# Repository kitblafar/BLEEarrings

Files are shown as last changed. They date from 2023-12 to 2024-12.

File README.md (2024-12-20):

# Bluetooth Low-Energy Earrings

A set of bluetooth BLE earrings inspired by the movie blade runner.

Including custom pendant, earring and earring charging dock PCBs; custom 3D printed enclosure; embedded solution on NRF52833 and bluetooth app.

This earring blink different colours dependant on messages sent over Bluetooth by the bluetooth app. The solution includes a pendant that holds the LED and is connected by wiring that passes through the ear piercing; the earring itself that sits behind the ear and a charging and programming dock including USB hub. The earrings are flashed and charged over USB C connectors and are powered by drone batteries so include custom charge protection and power path management circuits.

Project phase: PCB ordered and received, BOM finalised and ordered, first revision of enclosure made, first iteration of the embedded solution.

Next step: test PCBs and NRF52833 code, order batteries, print enclosure, start developing the app.

This is a collab with [Dominic Mason](https://github.com/dominicmason555/)

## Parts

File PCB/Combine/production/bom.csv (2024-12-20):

Designator | Footprint | Quantity | Value | LCSC Part #
ANT1, ANT2 | Texas_SWRA117D_2.4GHz_Left | 2 | ~ | N/A
BT1 | CONN-TH_S2B-PH-K-S-LF-SN | 1 | Battery Pimoroni 1200mAh | C173752
BT2, BT3 | CONN-TH_530480210 | 2 | Battery Gens ace 200mAh 1S 45C 3.7V | C505099
C1, C11, C13, C16, C19, C2, C20 | 0402 | 7 | 100n | C60474
C10, C9 | 0603 | 2 | 22u | C59461
C12, C14, C23, C3 | 0402 | 4 | 1u | C14445
C15, C17 | 0402 | 2 | 4.7u
C18 | 0402 | 1 | 100n
C21, C22 | 0402 | 2 | 18p | C5137554
C24, C26, C59, C61 | 0402 | 4 | 10u | C15525
C25, C30, C33, C41, C46, C49, C57, C60 | 0402 | 8 | 100n | C60474
C27, C32, C43, C48 | 0402 | 4 | 8p | C5448809
C28, C29, C31, C44, C45, C47 | 0402 | 6 | 4.7u | C307423
C34, C38, C50, C54 | 0402 | 4 | 1u | C14445
C35, C51 | 0402 | 2 | 1p | C880647
C36, C52 | 0402 | 2 | 100p | C5137573
C37, C53 | 0402 | 2 | 1.2p | C880658
C39, C55 | 0402 | 2 | NC | N/A
C4, C5 | 0402 | 2 | 2.2u | C12530
C40, C42, C56, C58 | 0402 | 4 | 12p | C696888
C6, C7 | 0402 | 2 | 4.7u | C307423
C63, C64 | 0402 | 2 | 100n | C5448809
C8 | 0402 | 1 | 10u | C15525
D1 | 0603 | 1 | LED
D10, D8 | 0603 | 2 | BLUE LED | C7371904
D11, D7 | 0603 | 2 | RED LED | C389517
D12, D13 | LED-SMD_4P-L1.6-W1.5_XL-1615RGBC-WS2812B | 2 | 2758
D2 | 0603 | 1 | BLUE RED | C389517
D3, D4, D5 | 0603 | 3 | BLUE LED | C7371904
D6, D9 | SOT-23-6_L2.9-W1.6-P0.95-LS2.8-BL | 2 | USBLC6-2SC6_C2687116 | C2687116
J1 | TYPE-C-SMD_C9900025773 | 1 | USB_C_Receptacle | C5156605
J2 | HDR-TH_10P-P1.27-V-M-R2-C5-S1.27-1 | 1 | Conn_01x10_Socket | C2935953
J3, J6 | TYPE-C-SMD_C9900025773 | 2 | USB_C_Receptacle | C5156605
J4, J7 | CONN-SMD_custom1 | 2 | Screw_Terminal_01x01 | C2765059
J5, J8 | CONN-SMD_2059-302 | 2 | Screw_Terminal_01x02 | C2765060
L1 | IND-SMD_L4.5-W4.1 | 1 | 4.7u | C22463808
L2, L4 | 0402 | 2 | 4.7n | C13595
L3, L5 | 0402 | 2 | 2.2n | C395061
P1, P2 | USB-C-SMD_TYPE-C-24P-GTJB-040 | 2 | USB_C_Plug | C2763095
R1, R24, R25, R38, R39, R4 | 0402 | 6 | 5k1 | C103086
R10 | 0402 | 1 | 2k | C3016052
R11, R12 | 0402 | 2 | 1k | C3016052
R13 | 0402 | 1 | 732 | C137939
R14 | 0402 | 1 | 100k | C60491
R15, R16, R29, R40 | 0402 | 4 | 220 | C112291
R17, R18, R19 | 0402 | 3 | 100 | C3015757
R20 | 0402 | 1 | 12k | C137923
R21, R22 | 0402 | 2 | 10k
R23, R9 | 0402 | 2 | 10k | C60490
R26, R37, R48, R49 | 0402 | 4 | 2k | C60488
R27, R50 | 0402 | 2 | 4k99 | C137965
R28, R51 | 0402 | 2 | 100 | C106233
R30, R31, R32, R33, R41, R42, R43, R44 | 0201 | 8 | NF | N/A
R34, R45 | 0402 | 2 | 100k | C60491
R35, R46 | 0402 | 2 | 33k | C138003
R36, R47 | 0402 | 2 | 470 | C114949
R5, R6 | 0402 | 2 | 1k | C60488
R7 | 0402 | 1 | 1.18k | C3016052
R8 | 0402 | 1 | 1.78k | C5121514
SW1, SW3 | SW-TH_TK-6580B-1 | 2 | TK-6580B-1 | C2689829
SW2, SW4 | KEY-SMD_L3.0-W2.5-LS4.0 | 2 | SW_DIP_x01 | C2905194
TP1, TP10, TP11, TP12, TP2, TP28, TP3, TP4, TP5, TP6, TP7, TP8, TP9, TPL3 | TestPoint_Pad_D1.0mm | 14 | TestPoint
TP13, TP14, TP15, TP17, TP18, TP19 | TestPoint_Pad_D1.0mm | 6 | TestPoint | N/A
TP16, TP20 | TestPoint_Pad_D2.0mm | 2 | TestPoint | N/A
TP21, TP22, TP23, TP24, TP25, TP26 | TestPoint_THTPad_D1.0mm_Drill0.5mm | 6 | TestPoint
U1 | SOT-223-3_TabPin2 | 1 | AMS1117-3.3 | N/A
U10, U9 | QFN-40_L5.0-W5.0-P0.40-TL-EP3.6 | 2 | NRF52833-QDAA-R7 | C3007767
U11, U7 | SOT-23-5_L3.0-W1.7-P0.95-LS2.8-BL | 2 | MCP73831T-2ACI/OT | C424093
U12, U8 | WDFN-6_L2.0-W2.0-P0.65-BL-EP | 2 | XB6096I2SV | C2998744
U2 | VQFN-16-1EP_3x3mm_P0.5mm_EP1.6x1.6mm | 1 | BQ24073RGT | C15220
U3 | SOT-563_L1.6-W1.2-P0.50-LS1.6-BR | 1 | TPS61023DRLR | C919459
U4, U6 | SOT-23-6_Handsoldering | 2 | SIP32509DT-T1-GE3 | C335619
U5 | HVQFN-24-1EP_4x4mm_P0.5mm_EP2.5x2.5mm_ThermalVias | 1 | USB2422T-I/MJ | C622610
Y1 | CRYSTAL-SMD_4P-L3.2-W2.5-BL | 1 | X322524MOB4SI | C70590
Y2, Y4 | CRYSTAL-SMD_L1.6-W1.0 | 2 | X161032768KLD2SI | C383846
Y3, Y5 | CRYSTAL-SMD_4P-L2.0-W1.6-BL | 2 | XL7EL89CKI-111YLC-32M | C2965582

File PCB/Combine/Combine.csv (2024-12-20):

Reference | Value | Footprint | Datasheet | Availability | Check_prices | Description | LCSC Part | MANUFACTURER | MAXIMUM_PACKAGE_HEIGHT | MF | MP | PARTREV | Package | Price | STANDARD | SnapEDA_Link | Qty
ANT1, ANT2 | ~ | RF_Antenna:Texas_SWRA117D_2.4GHz_Left |  |  |  |  | N/A |  |  |  |  |  |  |  |  |  | 2
BT1 | Battery Pimoroni 1200mAh | easyeda2kicad:CONN-TH_S2B-PH-K-S-LF-SN | ~ |  |  |  | C173752 |  |  |  |  |  |  |  |  |  | 1
BT2, BT3 | Battery Gens ace 200mAh 1S 45C 3.7V | easyeda2kicad:CONN-TH_530480210 | ~ |  |  |  | C505099 |  |  |  |  |  |  |  |  |  | 2
C1, C2, C11, C13, C16, C18-C20, C25, C30, C33, C41, C46, C49, C57, C60, C63, C64 | 100n | Capacitor_SMD:C_0402_1005Metric_Pad0.74x0.62mm_HandSolder | ~ |  |  |  | -- mixed values -- |  |  |  |  |  |  |  |  |  | 18
C3, C12, C14, C23, C34, C38, C50, C54 | 1u | Capacitor_SMD:C_0402_1005Metric_Pad0.74x0.62mm_HandSolder | ~ |  |  |  | -- mixed values -- |  |  |  |  |  |  |  |  |  | 8
C4, C5 | 2.2u | Capacitor_SMD:C_0402_1005Metric_Pad0.74x0.62mm_HandSolder | ~ |  |  |  | C12530 |  |  |  |  |  |  |  |  |  | 2
C6, C7, C15, C17, C28, C29, C31, C44, C45, C47 | 4.7u | Capacitor_SMD:C_0402_1005Metric_Pad0.74x0.62mm_HandSolder | ~ |  |  |  | -- mixed values -- |  |  |  |  |  |  |  |  |  | 10
C8, C24, C26, C59, C61 | 10u | Capacitor_SMD:C_0402_1005Metric_Pad0.74x0.62mm_HandSolder | ~ |  |  |  | -- mixed values -- |  |  |  |  |  |  |  |  |  | 5
C9, C10 | 22u | Capacitor_SMD:C_0603_1608Metric_Pad1.08x0.95mm_HandSolder | ~ |  |  |  | C59461 |  |  |  |  |  |  |  |  |  | 2
C21, C22 | 18p | Capacitor_SMD:C_0402_1005Metric_Pad0.74x0.62mm_HandSolder | ~ |  |  |  | C5137554 |  |  |  |  |  |  |  |  |  | 2
C27, C32, C43, C48 | 8p | Capacitor_SMD:C_0402_1005Metric_Pad0.74x0.62mm_HandSolder | ~ |  |  |  | C5448809 |  |  |  |  |  |  |  |  |  | 4
C35, C51 | 1p | Capacitor_SMD:C_0402_1005Metric_Pad0.74x0.62mm_HandSolder | ~ |  |  |  | C880647 |  |  |  |  |  |  |  |  |  | 2
C36, C52 | 100p | Capacitor_SMD:C_0402_1005Metric_Pad0.74x0.62mm_HandSolder | ~ |  |  |  | C5137573 |  |  |  |  |  |  |  |  |  | 2
C37, C53 | 1.2p | Capacitor_SMD:C_0402_1005Metric_Pad0.74x0.62mm_HandSolder | ~ |  |  |  | C880658 |  |  |  |  |  |  |  |  |  | 2
C39, C55 | NC | Capacitor_SMD:C_0402_1005Metric_Pad0.74x0.62mm_HandSolder | ~ |  |  |  | N/A |  |  |  |  |  |  |  |  |  | 2
C40, C42, C56, C58 | 12p | Capacitor_SMD:C_0402_1005Metric_Pad0.74x0.62mm_HandSolder | ~ |  |  |  | C696888 |  |  |  |  |  |  |  |  |  | 4
D1 | LED | LED_SMD:LED_0603_1608Metric_Pad1.05x0.95mm_HandSolder | ~ |  |  |  |  |  |  |  |  |  |  |  |  |  | 1
D2 | BLUE RED | easyeda2kicad:SideStuckLED | ~ |  |  |  | C389517 |  |  |  |  |  |  |  |  |  | 1
D3 | BLUE LED | easyeda2kicad:SideStuckLED | ~ |  |  |  | C7371904 |  |  |  |  |  |  |  |  |  | 1
D4, D5, D8, D10 | BLUE LED | LED_SMD:LED_0603_1608Metric_Pad1.05x0.95mm_HandSolder | ~ |  |  |  | -- mixed values -- |  |  |  |  |  |  |  |  |  | 4
D6, D9 | USBLC6-2SC6_C2687116 | easyeda2kicad:SOT-23-6_L2.9-W1.6-P0.95-LS2.8-BL |  |  |  |  | C2687116 |  |  |  |  |  |  |  |  |  | 2
D7, D11 | RED LED | LED_SMD:LED_0603_1608Metric_Pad1.05x0.95mm_HandSolder | ~ |  |  |  | C389517 |  |  |  |  |  |  |  |  |  | 2
D12, D13 | 2758 | easyeda2kicad:SOL320P540X170-4N |  | In Stock | https://www.snapeda.com/parts/2758/Adafruit+Industries+LLC/view-part/?ref=eda | Addressable Lighting Neopixel 10 LED Discrete Serial (Shift Register) Red, Green, Blue, Neutral White (RGBW) 5.00mm L x 5.00mm W |  | Adafruit Industries | 1.7 mm | Adafruit Industries | 2758 | 01 | SMD-4 Adafruit Industries | None | IPC 7351B | https://www.snapeda.com/parts/2758/Adafruit+Industries+LLC/view-part/?ref=snap | 2
J1, J3, J6 | USB_C_Receptacle | easyeda2kicad:TYPE-C-SMD_C9900025773 | https://www.usb.org/sites/default/files/documents/usb_type-c.zip |  |  |  | -- mixed values -- |  |  |  |  |  |  |  |  |  | 3
J2 | Conn_01x10_Socket | easyeda2kicad:HDR-TH_10P-P1.27-V-M-R2-C5-S1.27-1 | ~ |  |  |  | C2935953 |  |  |  |  |  |  |  |  |  | 1
J4, J7 | Screw_Terminal_01x01 | easyeda2kicad:CONN-SMD_custom1 | ~ |  |  |  | C2765059 |  |  |  |  |  |  |  |  |  | 2
J5, J8 | Screw_Terminal_01x02 | easyeda2kicad:CONN-SMD_2059-302 | ~ |  |  |  | C2765060 |  |  |  |  |  |  |  |  |  | 2
L1 | 4.7u | easyeda2kicad:IND-SMD_L4.4-W4.2 | ~ |  |  |  | C2836880 |  |  |  |  |  |  |  |  |  | 1
L2, L4 | 4.7n | Inductor_SMD:L_0402_1005Metric_Pad0.77x0.64mm_HandSolder | ~ |  |  |  | C13595 |  |  |  |  |  |  |  |  |  | 2
L3, L5 | 2.2n | Inductor_SMD:L_0402_1005Metric_Pad0.77x0.64mm_HandSolder | ~ |  |  |  | C395061 |  |  |  |  |  |  |  |  |  | 2
P1, P2 | USB_C_Plug | easyeda2kicad:USB-C-SMD_TYPE-C-24P-GTJB-040 | https://www.usb.org/sites/default/files/documents/usb_type-c.zip |  |  |  | C2763095 |  |  |  |  |  |  |  |  |  | 2
R1, R4, R24, R25, R38, R39 | 5k1 | Resistor_SMD:R_0402_1005Metric_Pad0.72x0.64mm_HandSolder | ~ |  |  |  | C103086 |  |  |  |  |  |  |  |  |  | 6
R2, R3 | 0R | Resistor_SMD:R_0805_2012Metric_Pad1.20x1.40mm_HandSolder | ~ |  |  |  |  |  |  |  |  |  |  |  |  |  | 2
R5, R6 | 1k | Resistor_SMD:R_0402_1005Metric_Pad0.72x0.64mm_HandSolder | ~ |  |  |  | C60488 |  |  |  |  |  |  |  |  |  | 2
R7, R11, R12 | 1.18k | Resistor_SMD:R_0402_1005Metric_Pad0.72x0.64mm_HandSolder | ~ |  |  |  | C3016052 |  |  |  |  |  |  |  |  |  | 3
R8 | 1.78k | Resistor_SMD:R_0402_1005Metric_Pad0.72x0.64mm_HandSolder | ~ |  |  |  | C5121514 |  |  |  |  |  |  |  |  |  | 1
R9, R21-R23 | 10k | Resistor_SMD:R_0402_1005Metric_Pad0.72x0.64mm_HandSolder | ~ |  |  |  | -- mixed values -- |  |  |  |  |  |  |  |  |  | 4
R10, R26, R37, R48, R49 | 2k | Resistor_SMD:R_0402_1005Metric_Pad0.72x0.64mm_HandSolder | ~ |  |  |  | -- mixed values -- |  |  |  |  |  |  |  |  |  | 5
R13 | 732 | Resistor_SMD:R_0402_1005Metric_Pad0.72x0.64mm_HandSolder | ~ |  |  |  | C137939 |  |  |  |  |  |  |  |  |  | 1
R14, R34, R45 | 100k | Resistor_SMD:R_0402_1005Metric_Pad0.72x0.64mm_HandSolder | ~ |  |  |  | -- mixed values -- |  |  |  |  |  |  |  |  |  | 3
R15, R16, R29, R40 | 220 | Resistor_SMD:R_0402_1005Metric_Pad0.72x0.64mm_HandSolder | ~ |  |  |  | C112291 |  |  |  |  |  |  |  |  |  | 4
R17-R19, R28, R51 | 100 | Resistor_SMD:R_0402_1005Metric_Pad0.72x0.64mm_HandSolder | ~ |  |  |  | -- mixed values -- |  |  |  |  |  |  |  |  |  | 5
R20 | 12k | Resistor_SMD:R_0402_1005Metric_Pad0.72x0.64mm_HandSolder | ~ |  |  |  | C137923 |  |  |  |  |  |  |  |  |  | 1
R27, R50 | 4k99 | Resistor_SMD:R_0402_1005Metric_Pad0.72x0.64mm_HandSolder | ~ |  |  |  | C137965 |  |  |  |  |  |  |  |  |  | 2
R30-R33, R41-R44 | NF | Resistor_SMD:R_0201_0603Metric | ~ |  |  |  | N/A |  |  |  |  |  |  |  |  |  | 8
R35, R46 | 33k | Resistor_SMD:R_0402_1005Metric_Pad0.72x0.64mm_HandSolder | ~ |  |  |  | C138003 |  |  |  |  |  |  |  |  |  | 2
R36, R47 | 470 | Resistor_SMD:R_0402_1005Metric_Pad0.72x0.64mm_HandSolder | ~ |  |  |  | C114949 |  |  |  |  |  |  |  |  |  | 2
SW1, SW3 | TK-6580B-1 | easyeda2kicad:SW-TH_TK-6580B-1 |  |  |  |  | C2689829 |  |  |  |  |  |  |  |  |  | 2
SW2, SW4 | SW_DIP_x01 | easyeda2kicad:KEY-SMD_L3.0-W2.5-LS4.0 | ~ |  |  |  | C2905194 |  |  |  |  |  |  |  |  |  | 2
TP1-TP15, TP17-TP19 | TestPoint | TestPoint:TestPoint_Pad_D1.0mm | ~ |  |  |  | -- mixed values -- |  |  |  |  |  |  |  |  |  | 18
TP16, TP20, TP27 | TestPoint | TestPoint:TestPoint_Pad_D2.0mm | ~ |  |  |  | N/A |  |  |  |  |  |  |  |  |  | 3
TP21-TP26 | TestPoint | TestPoint:TestPoint_THTPad_D1.0mm_Drill0.5mm | ~ |  |  |  |  |  |  |  |  |  |  |  |  |  | 6
U1 | AMS1117-3.3 | Package_TO_SOT_SMD:SOT-223-3_TabPin2 | http://www.advanced-monolithic.com/pdf/ds1117.pdf |  |  |  | N/A |  |  |  |  |  |  |  |  |  | 1
U2 | BQ24073RGT | Package_DFN_QFN:VQFN-16-1EP_3x3mm_P0.5mm_EP1.6x1.6mm | http://www.ti.com/lit/ds/symlink/bq24073.pdf |  |  |  | C15220 |  |  |  |  |  |  |  |  |  | 1
U3 | TPS61023DRLR | easyeda2kicad:SOT-563_L1.6-W1.2-P0.50-LS1.6-BR |  |  |  |  | C919459 |  |  |  |  |  |  |  |  |  | 1
U4, U6 | SIP32509DT-T1-GE3 | Package_TO_SOT_SMD:SOT-23-6_Handsoldering | https://lcsc.com/product-detail/Others_Vishay-Intertech-SIP32509DT-T1-GE3_C335619.html |  |  |  | C335619 |  |  |  |  |  |  |  |  |  | 2
U5 | USB2422T-I/MJ | Package_DFN_QFN:HVQFN-24-1EP_4x4mm_P0.5mm_EP2.5x2.5mm_ThermalVias |  |  |  |  | C622610 |  |  |  |  |  |  |  |  |  | 1
U7, U11 | MCP73831T-2ACI/OT | easyeda2kicad:SOT-23-5_L3.0-W1.7-P0.95-LS2.8-BL | https://lcsc.com/product-detail/PMIC-Battery-Management_Microchip-Tech-MCP73831T-2ACI-OT_C424093.html |  |  |  | C424093 |  |  |  |  |  |  |  |  |  | 2
U8, U12 | XB6096I2SV | easyeda2kicad:WDFN-6_L2.0-W2.0-P0.65-BL-EP |  |  |  |  | C2998744 |  |  |  |  |  |  |  |  |  | 2
U9, U10 | NRF52833-QDAA-R7 | easyeda2kicad:QFN-40_L5.0-W5.0-P0.40-TL-EP3.6 |  |  |  |  | C3007767 |  |  |  |  |  |  |  |  |  | 2
Y1 | X322524MOB4SI | easyeda2kicad:CRYSTAL-SMD_4P-L3.2-W2.5-BL | ~ |  |  |  | C70590 |  |  |  |  |  |  |  |  |  | 1
Y2, Y4 | X161032768KLD2SI | easyeda2kicad:CRYSTAL-SMD_L1.6-W1.0 | ~ |  |  |  | C383846 |  |  |  |  |  |  |  |  |  | 2
Y3, Y5 | XL7EL89CKI-111YLC-32M | easyeda2kicad:CRYSTAL-SMD_4P-L2.0-W1.6-BL | ~ |  |  |  | C2965582 |  |  |  |  |  |  |  |  |  | 2

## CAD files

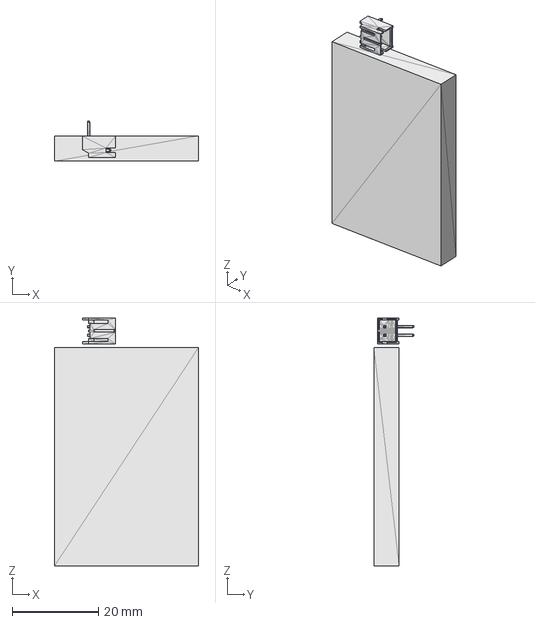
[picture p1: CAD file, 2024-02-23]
CAD/CustomParts/Battery/BatteryDock.STEP
33.5 x 9.40 x 57.6 mm

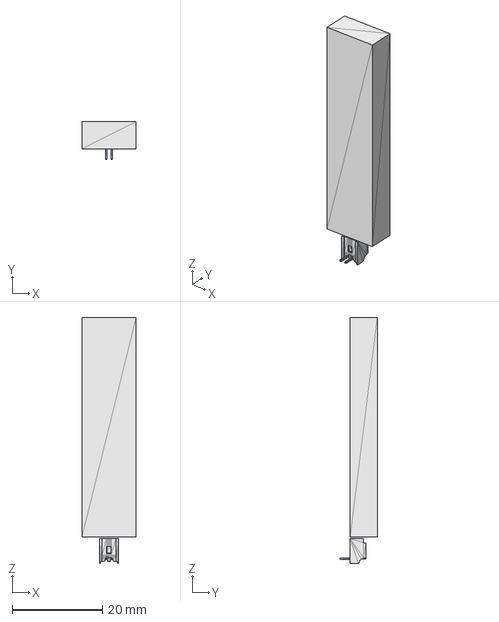
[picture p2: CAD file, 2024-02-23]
CAD/CustomParts/Battery/Earring/BatteryGens.STEP
12.0 x 8.30 x 54.4 mm

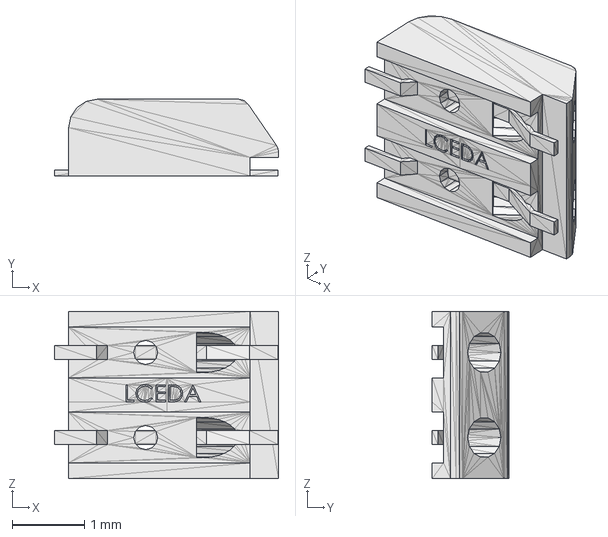
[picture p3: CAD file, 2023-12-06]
CAD/CustomParts/Connector/2Way/2wayconn.step
3.11 x 1.06 x 2.32 mm

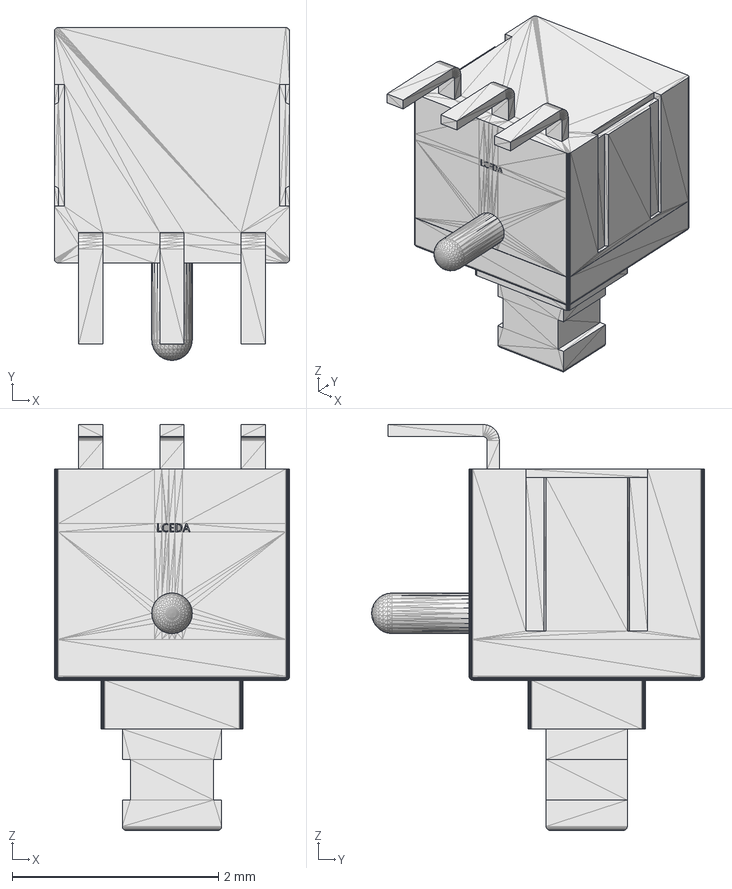
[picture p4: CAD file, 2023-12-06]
CAD/CustomParts/Switch/Switch.step
2.28 x 3.23 x 3.94 mm

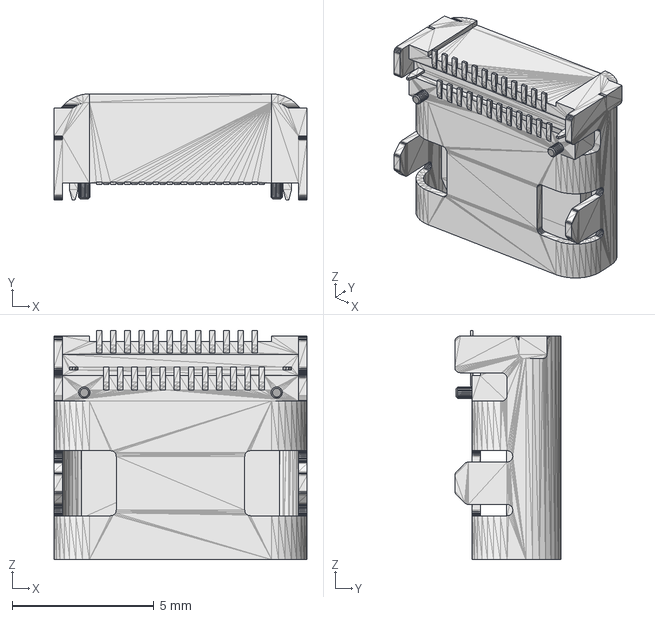
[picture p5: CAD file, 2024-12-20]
CAD/CustomParts/USB-C/USBC.step
8.94 x 3.76 x 8.10 mm

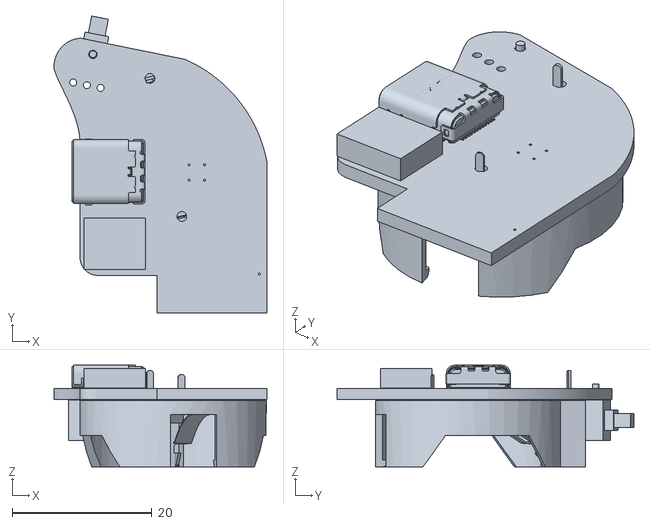
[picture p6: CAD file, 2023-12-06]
CAD/Earrings.stl
30.5 x 42.5 x 14.6

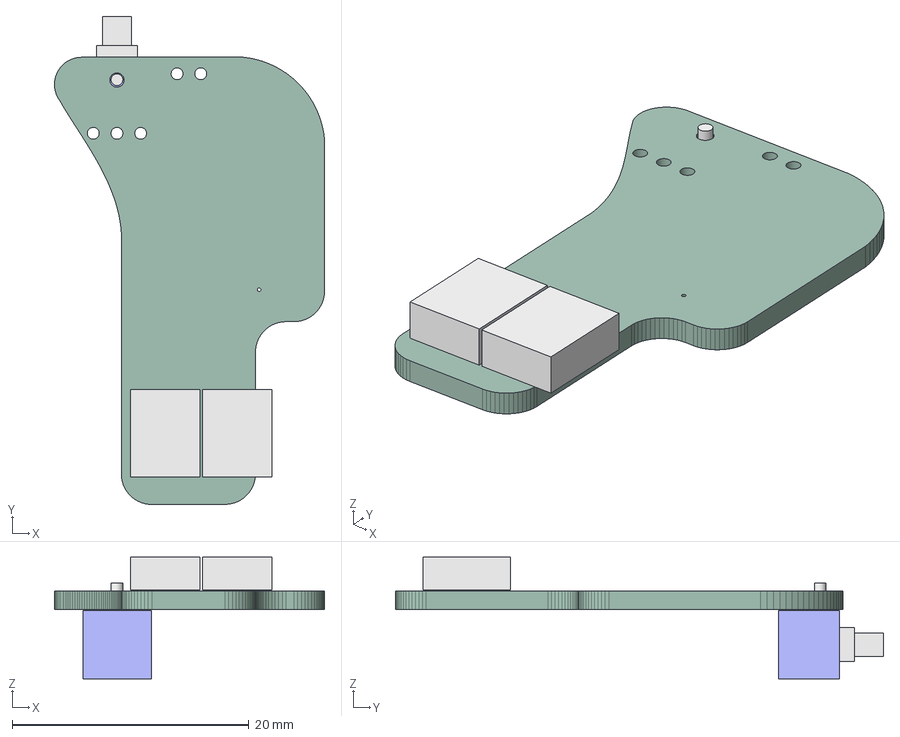
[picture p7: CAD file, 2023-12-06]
KiCADWork/BLEEarrings nRF52832/BLEEarrings.step
22.8 x 41.2 x 10.3 mm
_autosave-BLEEarrings PCB

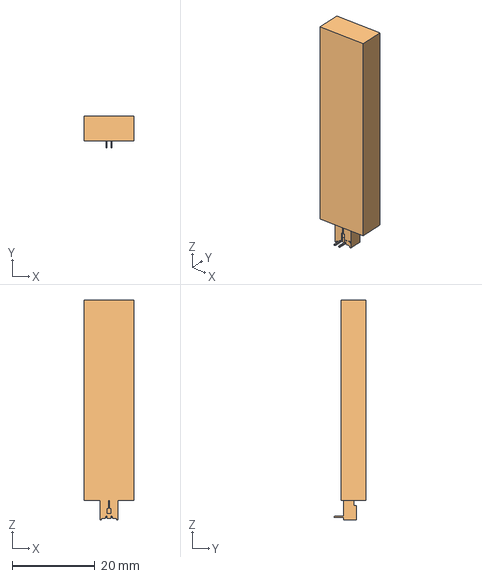
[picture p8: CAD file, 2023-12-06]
CAD/CustomParts/Battery/Earring/Battery.FCStd
12.0 x 7.72 x 53.3 mm
BatteryGens001
BatteryGens

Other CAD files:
CAD/CustomParts/Battery/BatteryDock.blend
CAD/CustomParts/Battery/BatteryDock.stl
CAD/CustomParts/Battery/Earring.blend
CAD/CustomParts/Battery/Earring/BatteryGens.blend
CAD/CustomParts/Battery/Earring/BatteryGens.stl
CAD/CustomParts/Connector/2Way/2Wayconn.FCStd
CAD/CustomParts/Connector/2Way/2wayconn.blend
CAD/CustomParts/Connector/2Way/2wayconn.stl
CAD/CustomParts/Switch/Switch.FCStd
CAD/CustomParts/Switch/Switch.blend
CAD/CustomParts/Switch/Switch.stl
CAD/CustomParts/USB-C/USBC.FCStd
CAD/CustomParts/USB-C/USBC.blend
CAD/CustomParts/USB-C/USBC.stl

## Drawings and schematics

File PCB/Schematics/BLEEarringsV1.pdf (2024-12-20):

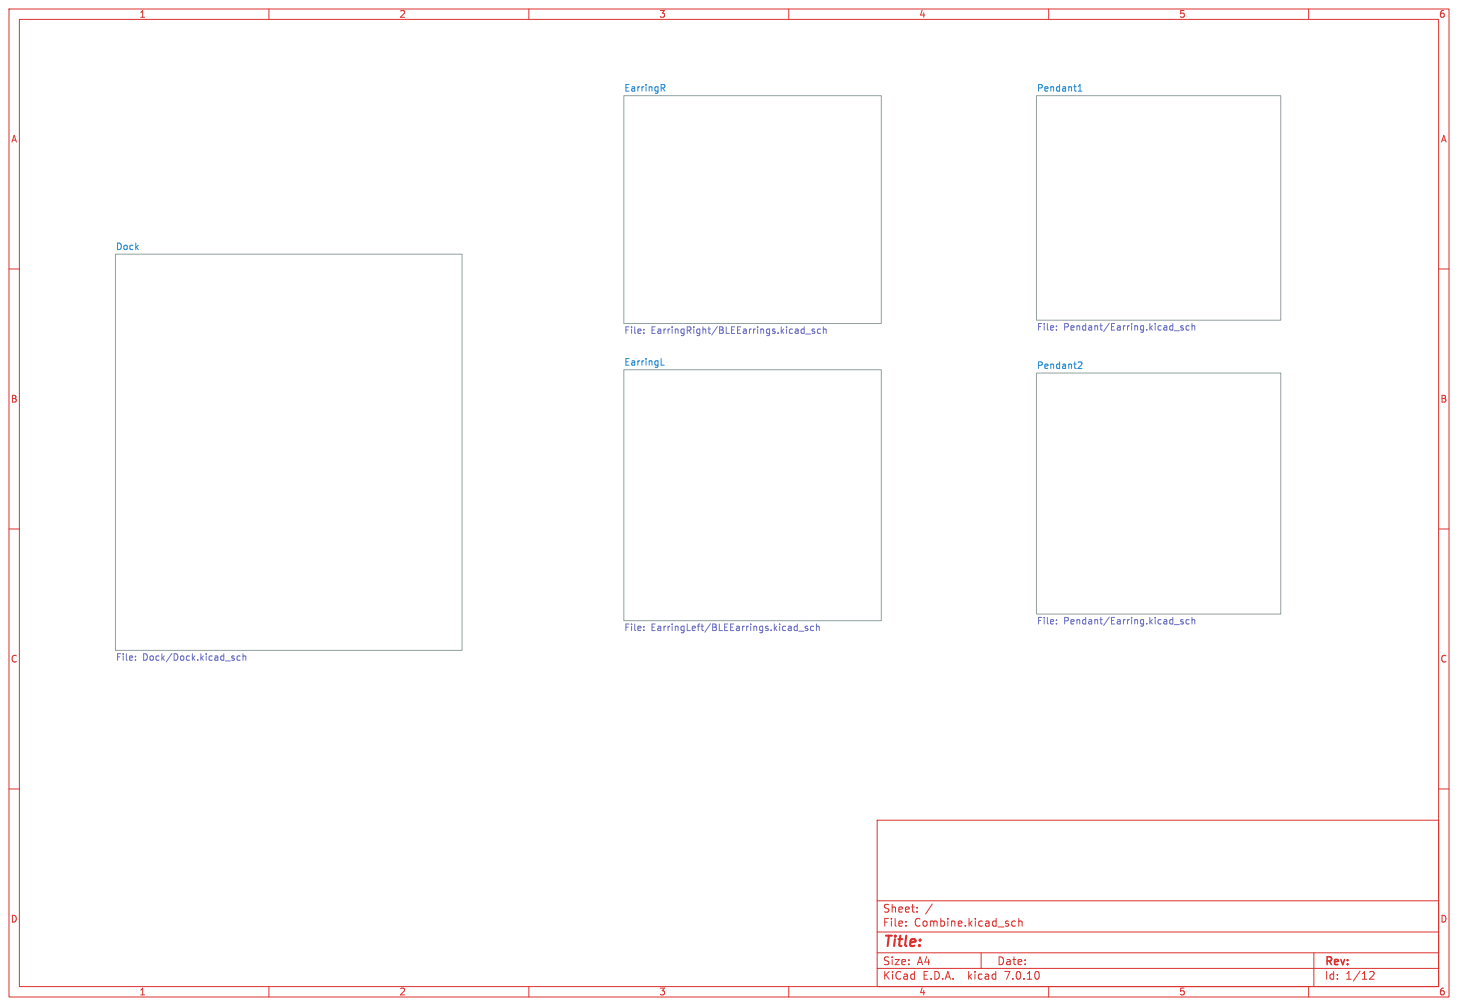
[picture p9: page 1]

EarringL File: EarringLeft/BLEEarrings.kicad_sch

Id: 1/12 Title: File: Combine.kicad_sch Sheet: /

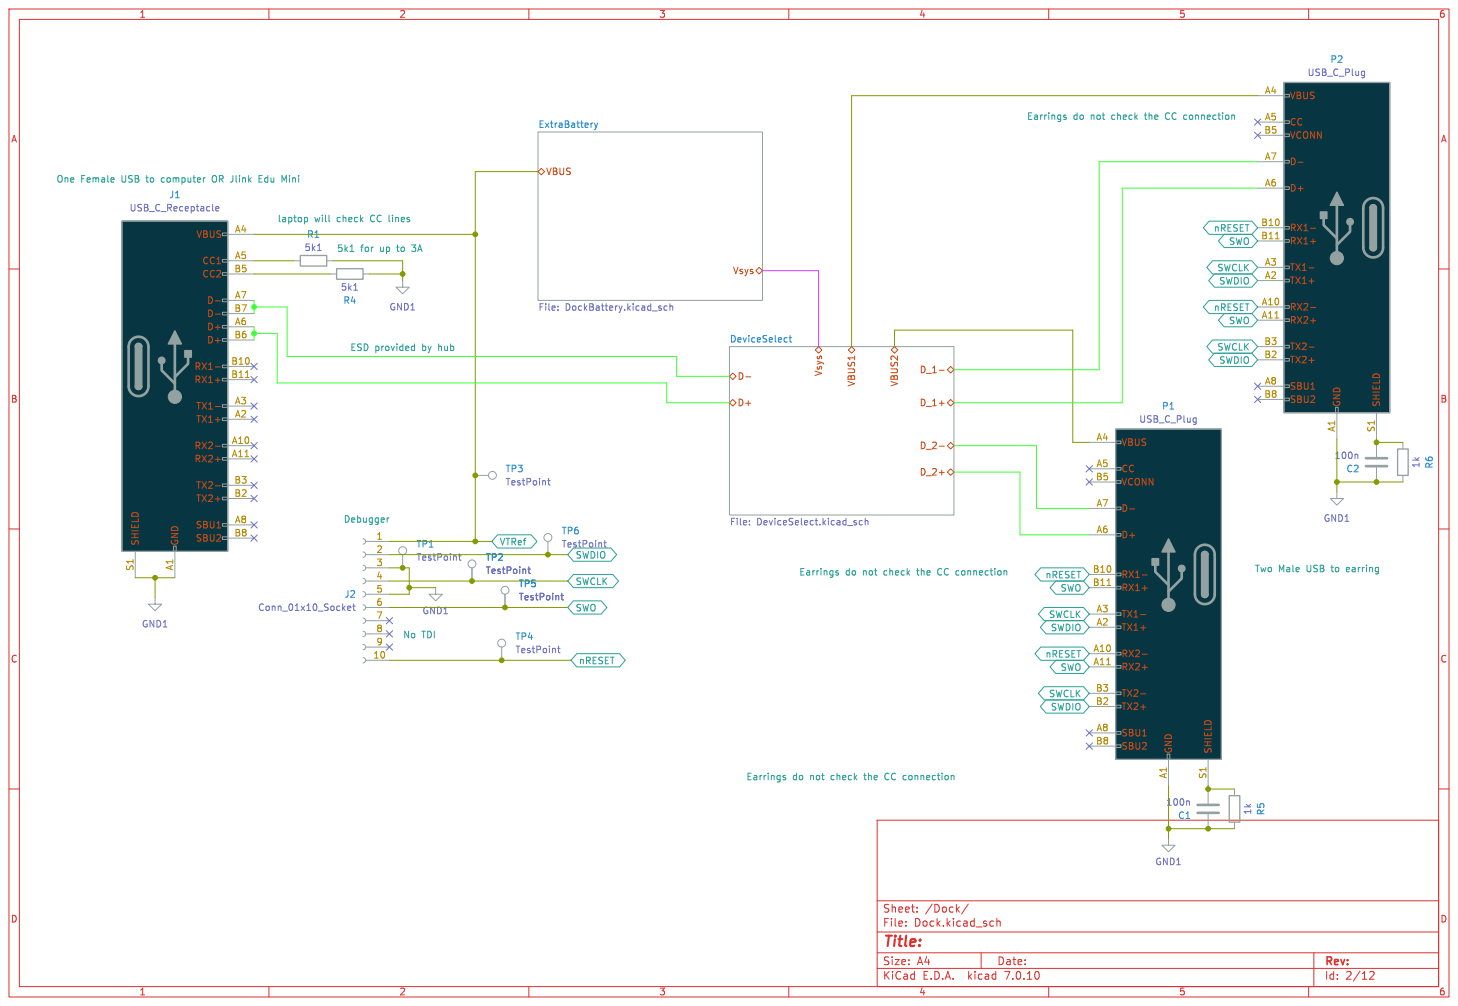
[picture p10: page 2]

Earrings do not check the CC connection

Id: 2/12 Title: File: Dock.kicad_sch Sheet: /Dock/

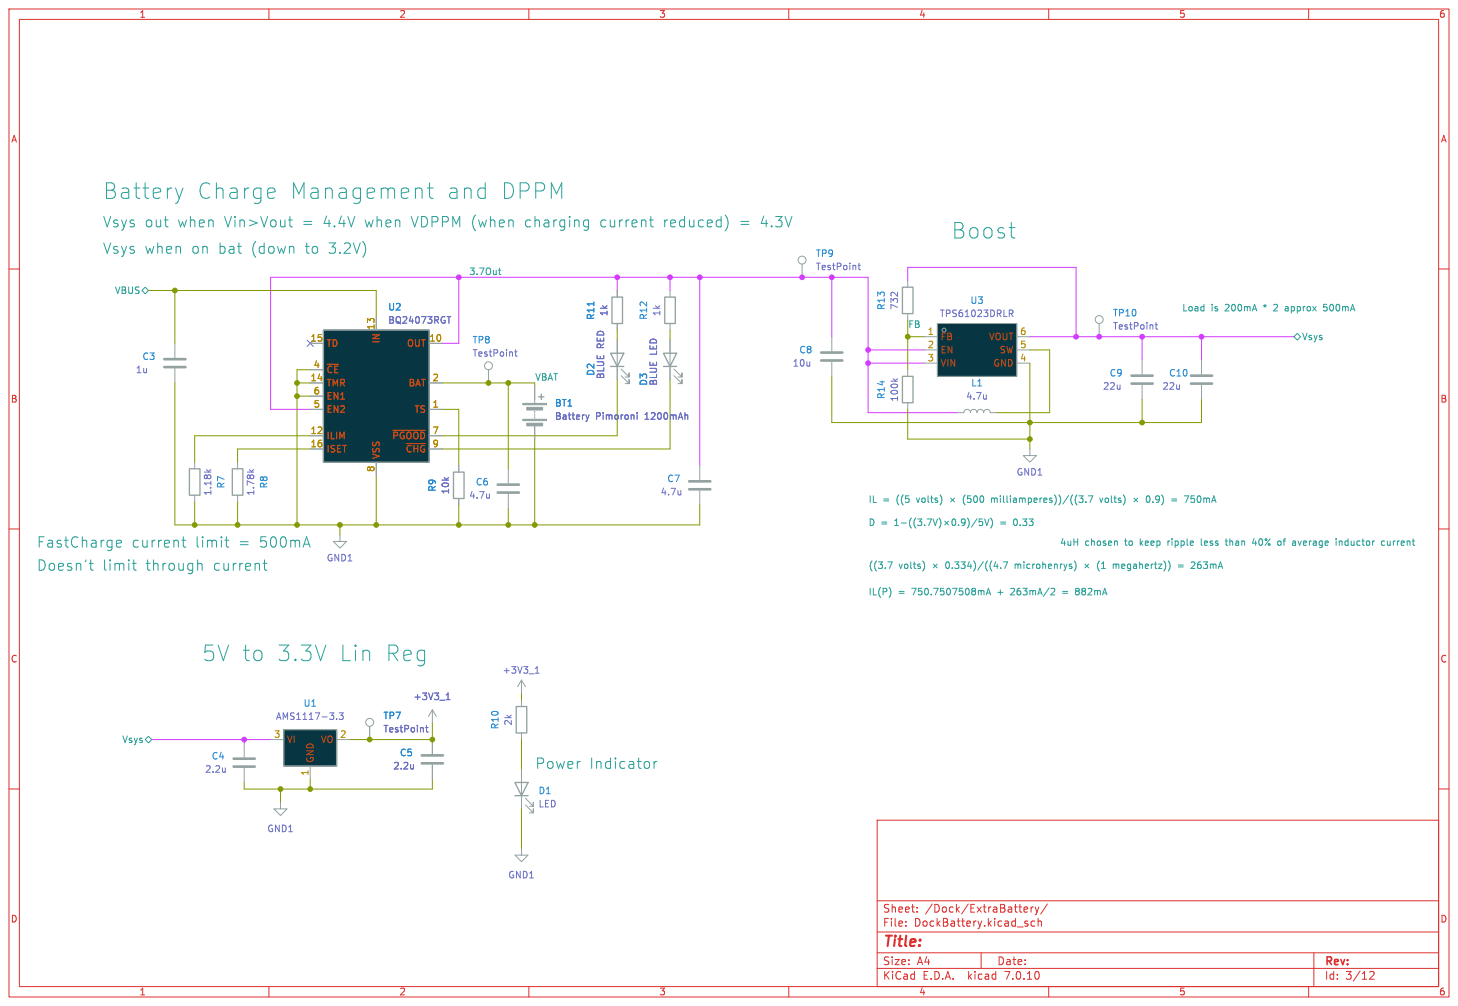
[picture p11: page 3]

Battery Charge Management and DPPM

Load is 200mA * 2 approx 500mA Vsys out when Vin>Vout = 4.4V when VDPPM (when charging current reduced) = 4.3V
Vsys when on bat (down to 3.2V)

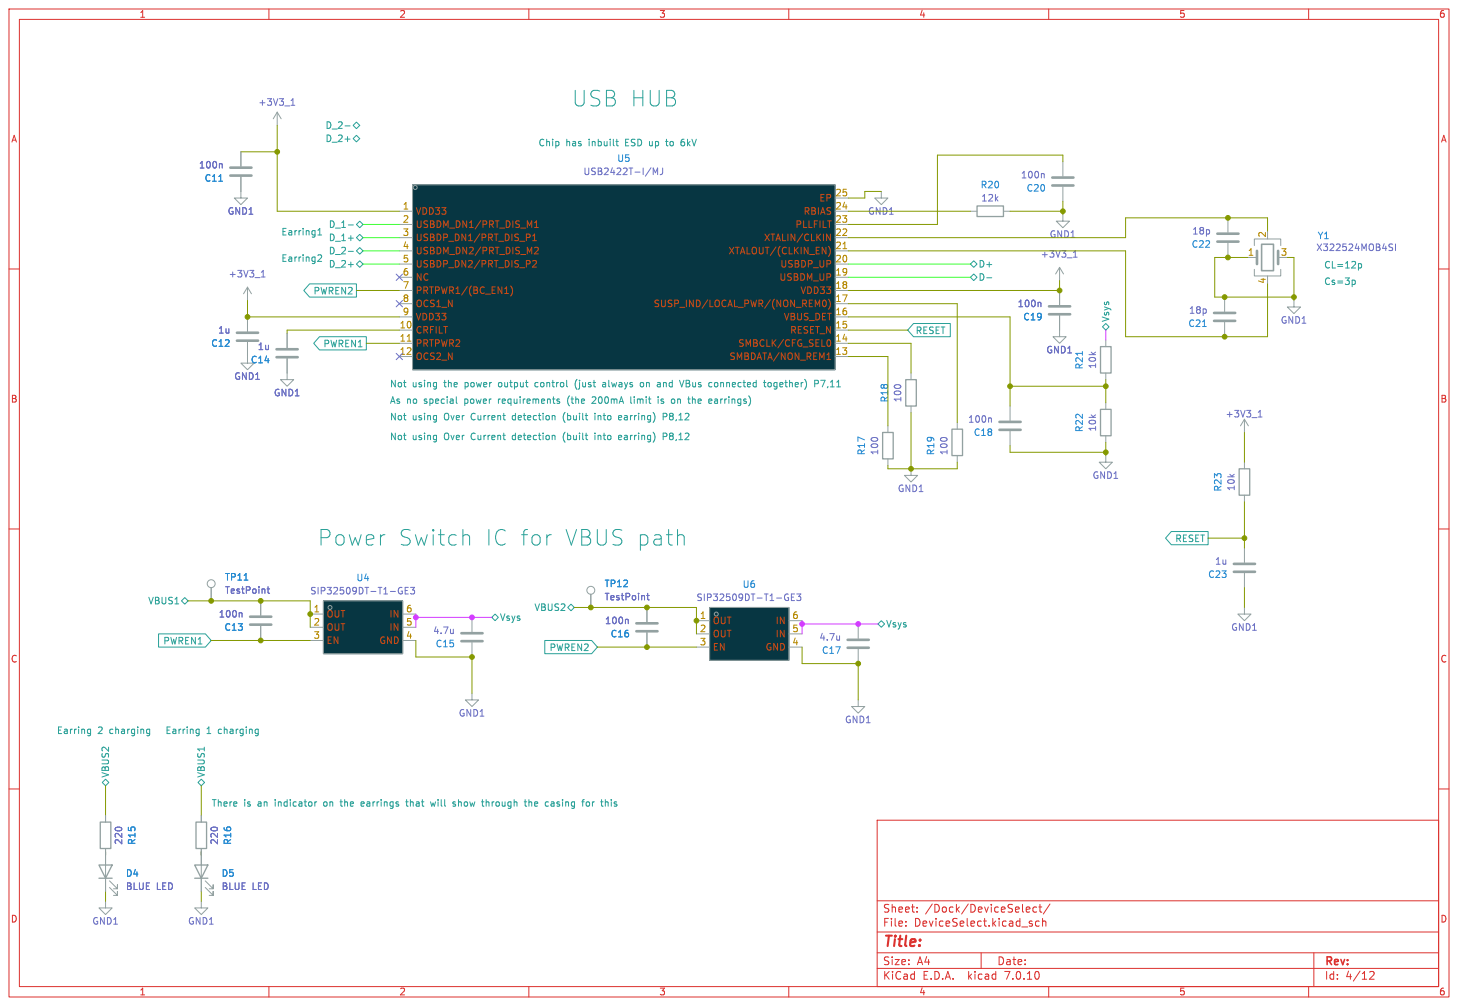
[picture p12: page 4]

Power Switch IC for VBUS path

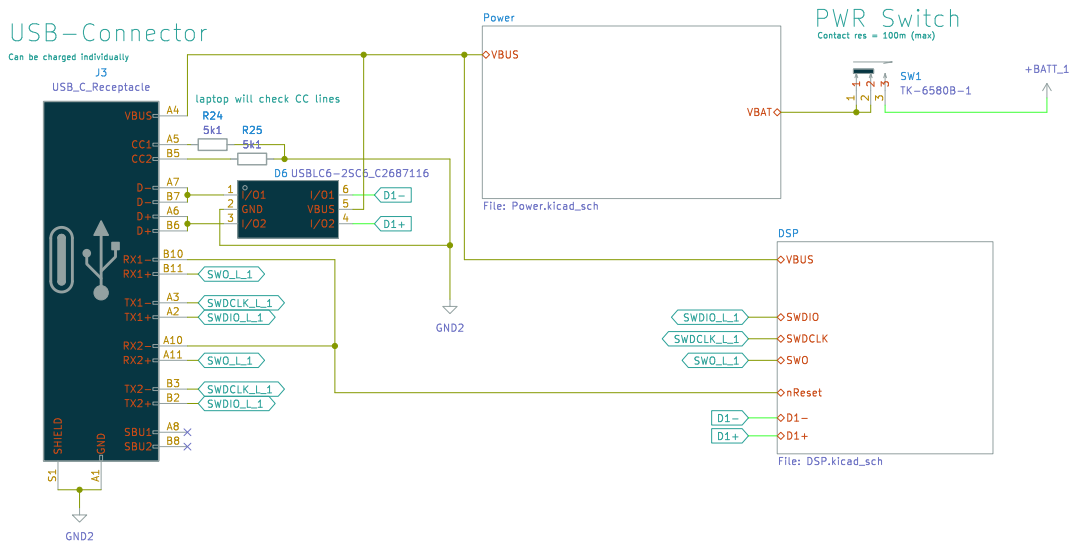
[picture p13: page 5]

VBAT Power File: Power.kicad_sch

Contact res = 100m (max) Can be charged individually USB-Connector

laptop will check CC lines R24

Id: 5/12 Title: BLEEarrings (Blade Runner) File: BLEEarrings.kicad_sch Sheet: /EarringR/

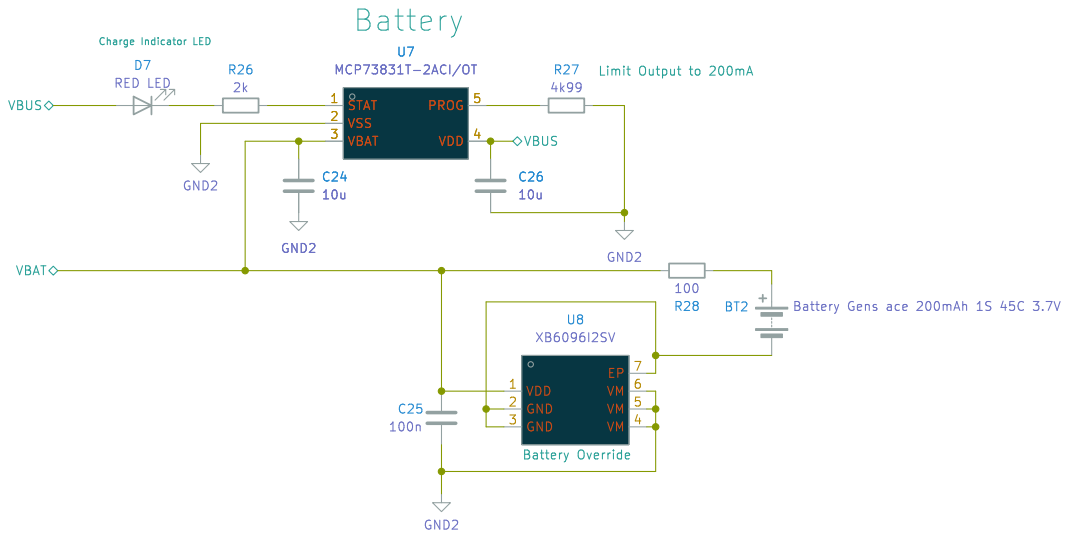
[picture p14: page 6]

Id: 5/12 Title: BLEEarrings (Blade Runner) File: Power.kicad_sch Sheet: /EarringR/Power/

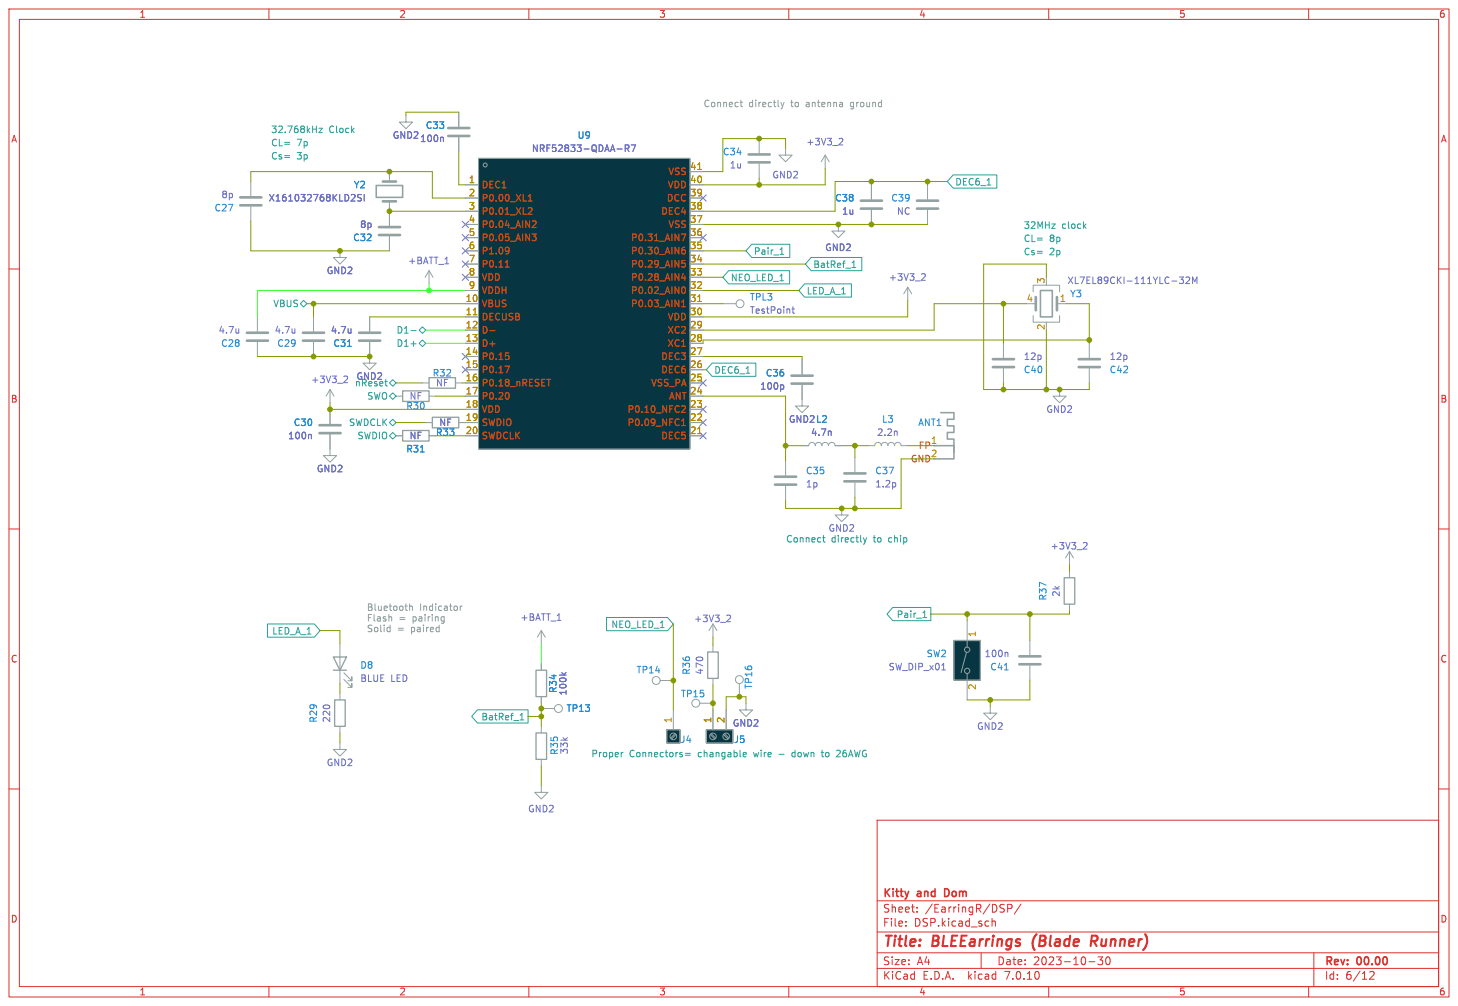
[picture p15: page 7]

Id: 6/12 Title: BLEEarrings (Blade Runner) File: DSP.kicad_sch Sheet: /EarringR/DSP/

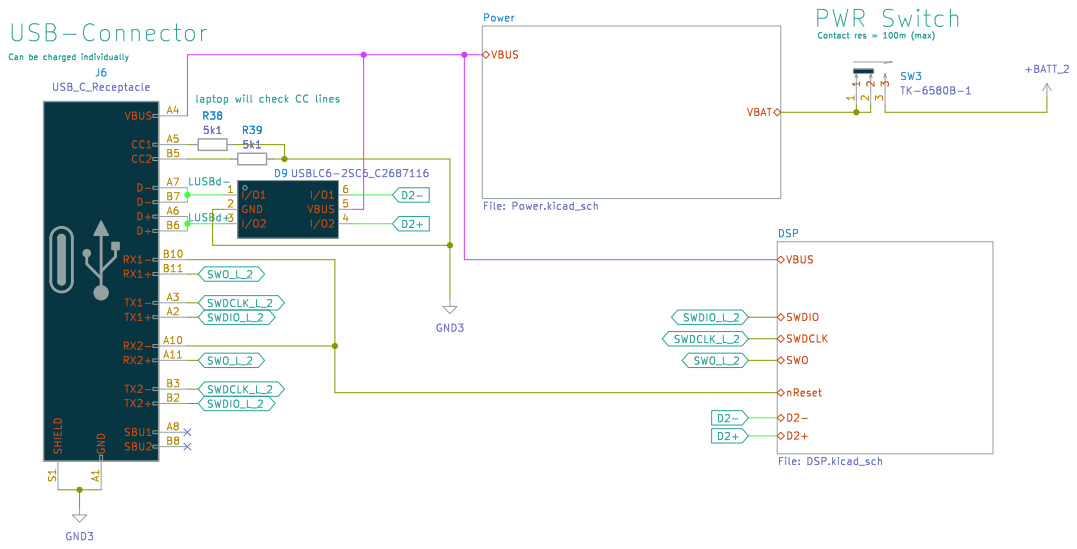
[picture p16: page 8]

Contact res = 100m (max) PWR Switch

laptop will check CC lines R38

Id: 7/12 Title: BLEEarrings (Blade Runner) File: BLEEarrings.kicad_sch Sheet: /EarringL/

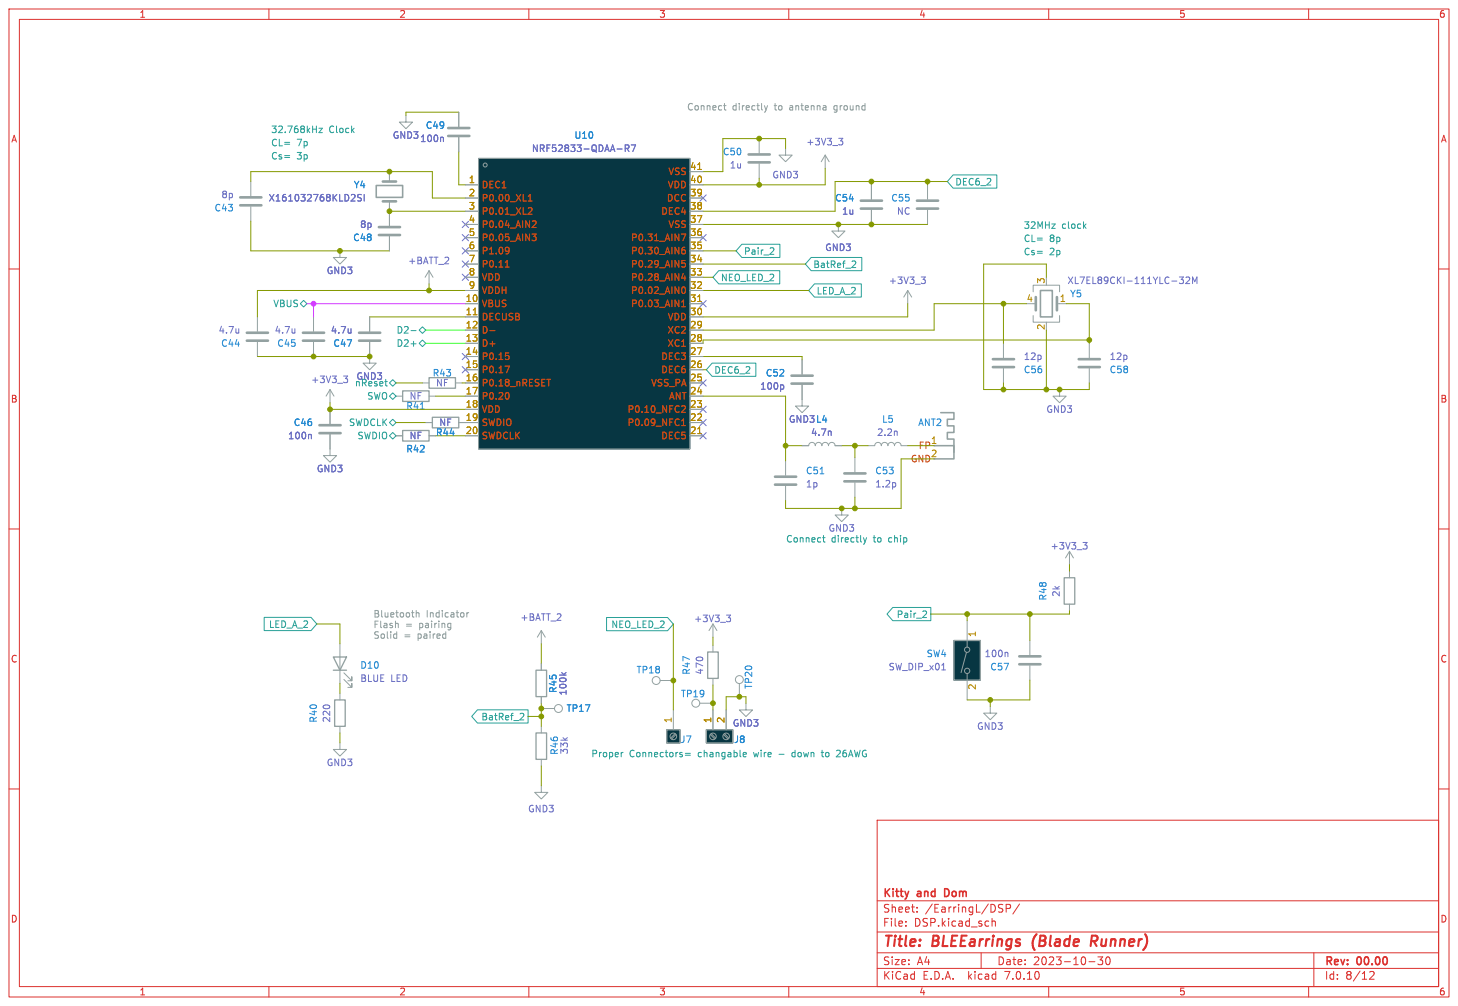
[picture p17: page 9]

Id: 8/12 Title: BLEEarrings (Blade Runner) File: DSP.kicad_sch Sheet: /EarringL/DSP/

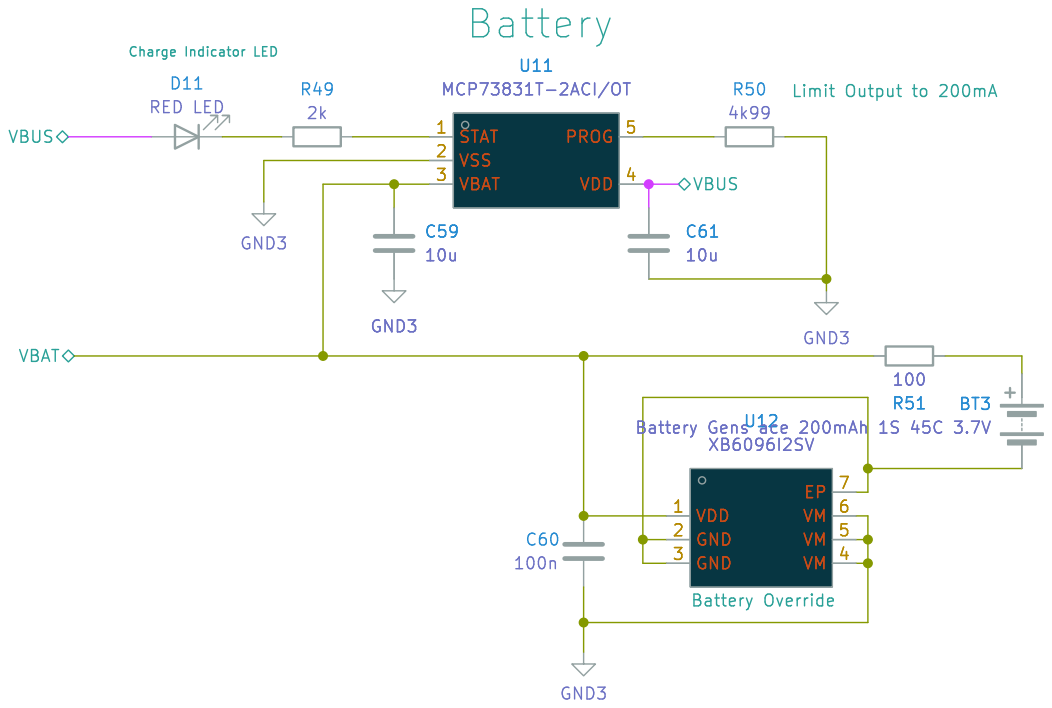
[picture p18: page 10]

Id: 9/12 Title: BLEEarrings (Blade Runner) File: Power.kicad_sch Sheet: /EarringL/Power/

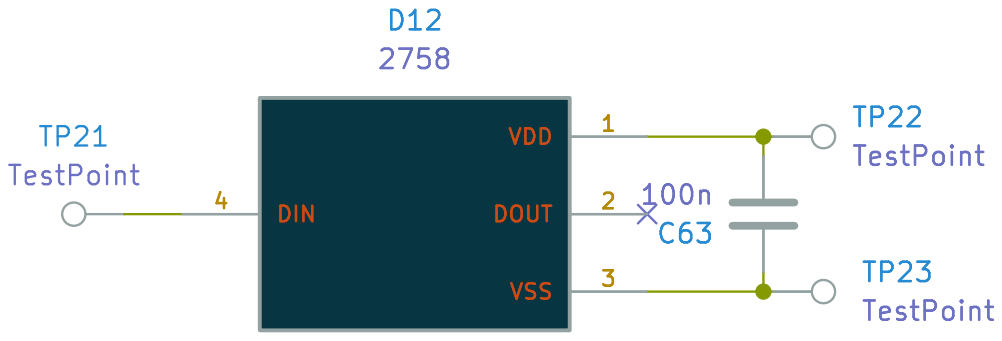
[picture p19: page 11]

Id: 10/12 Title: File: Earring.kicad_sch Sheet: /Pendant2/

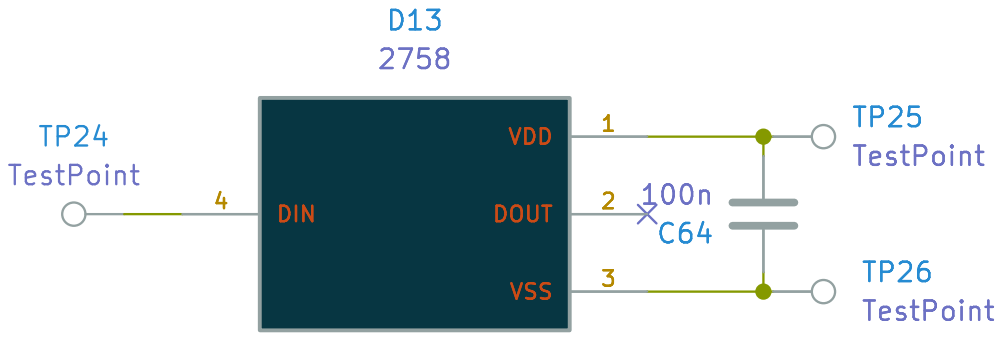
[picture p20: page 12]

Id: 11/12 Title: File: Earring.kicad_sch Sheet: /Pendant1/

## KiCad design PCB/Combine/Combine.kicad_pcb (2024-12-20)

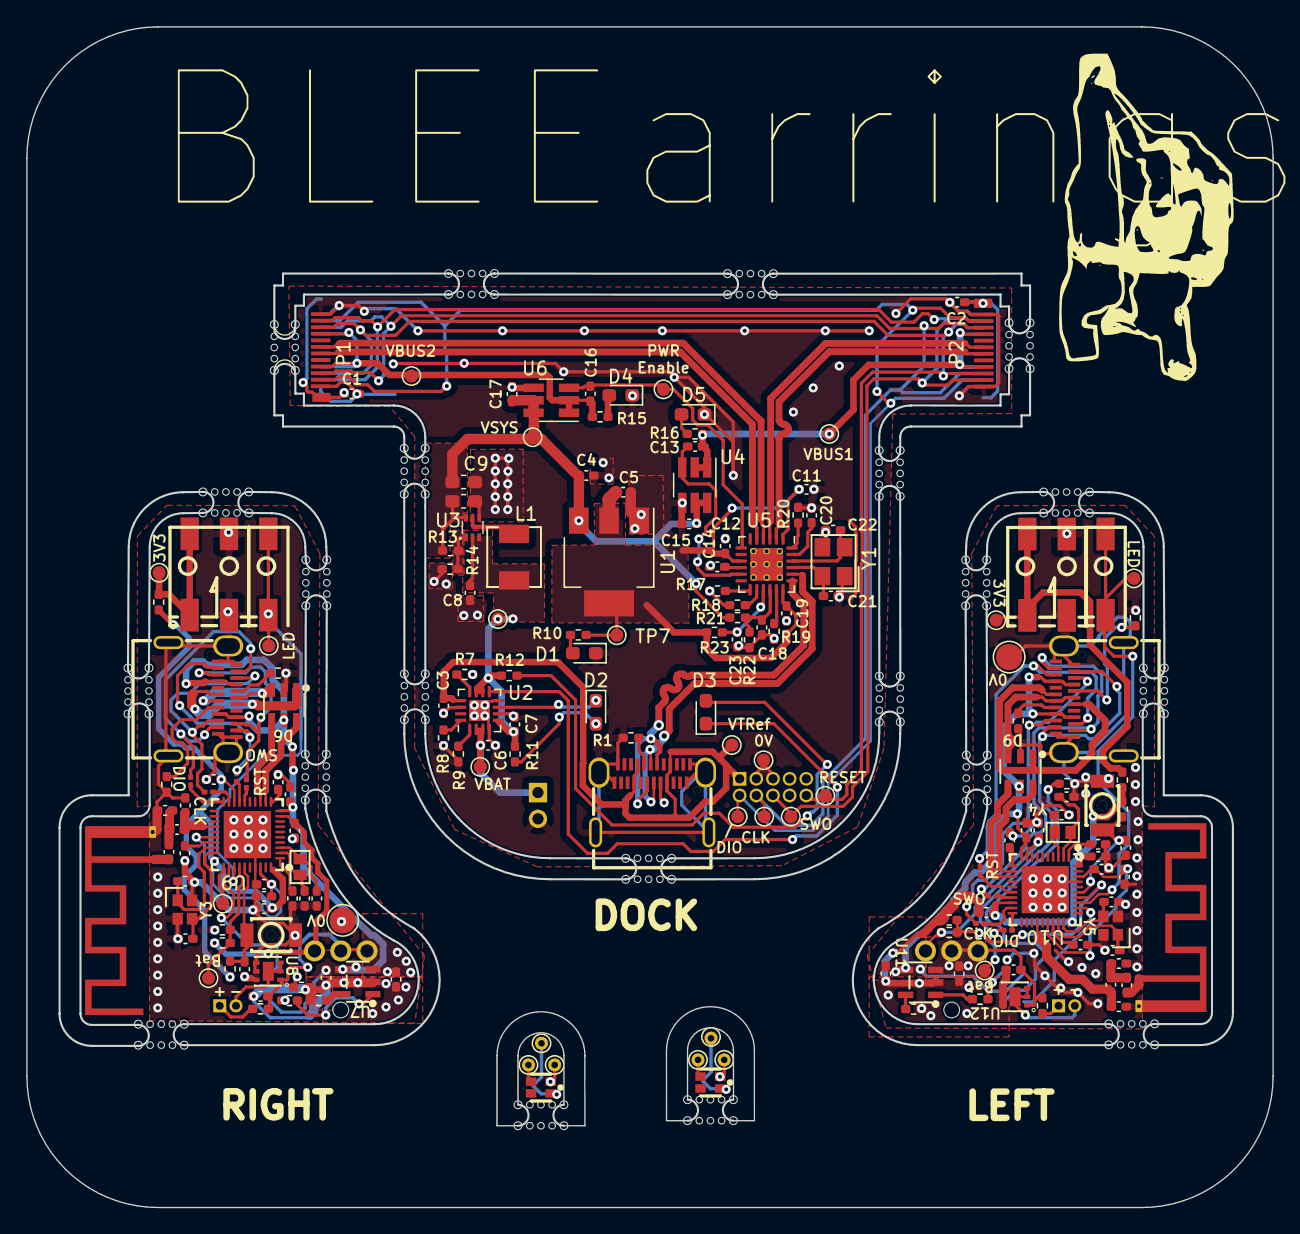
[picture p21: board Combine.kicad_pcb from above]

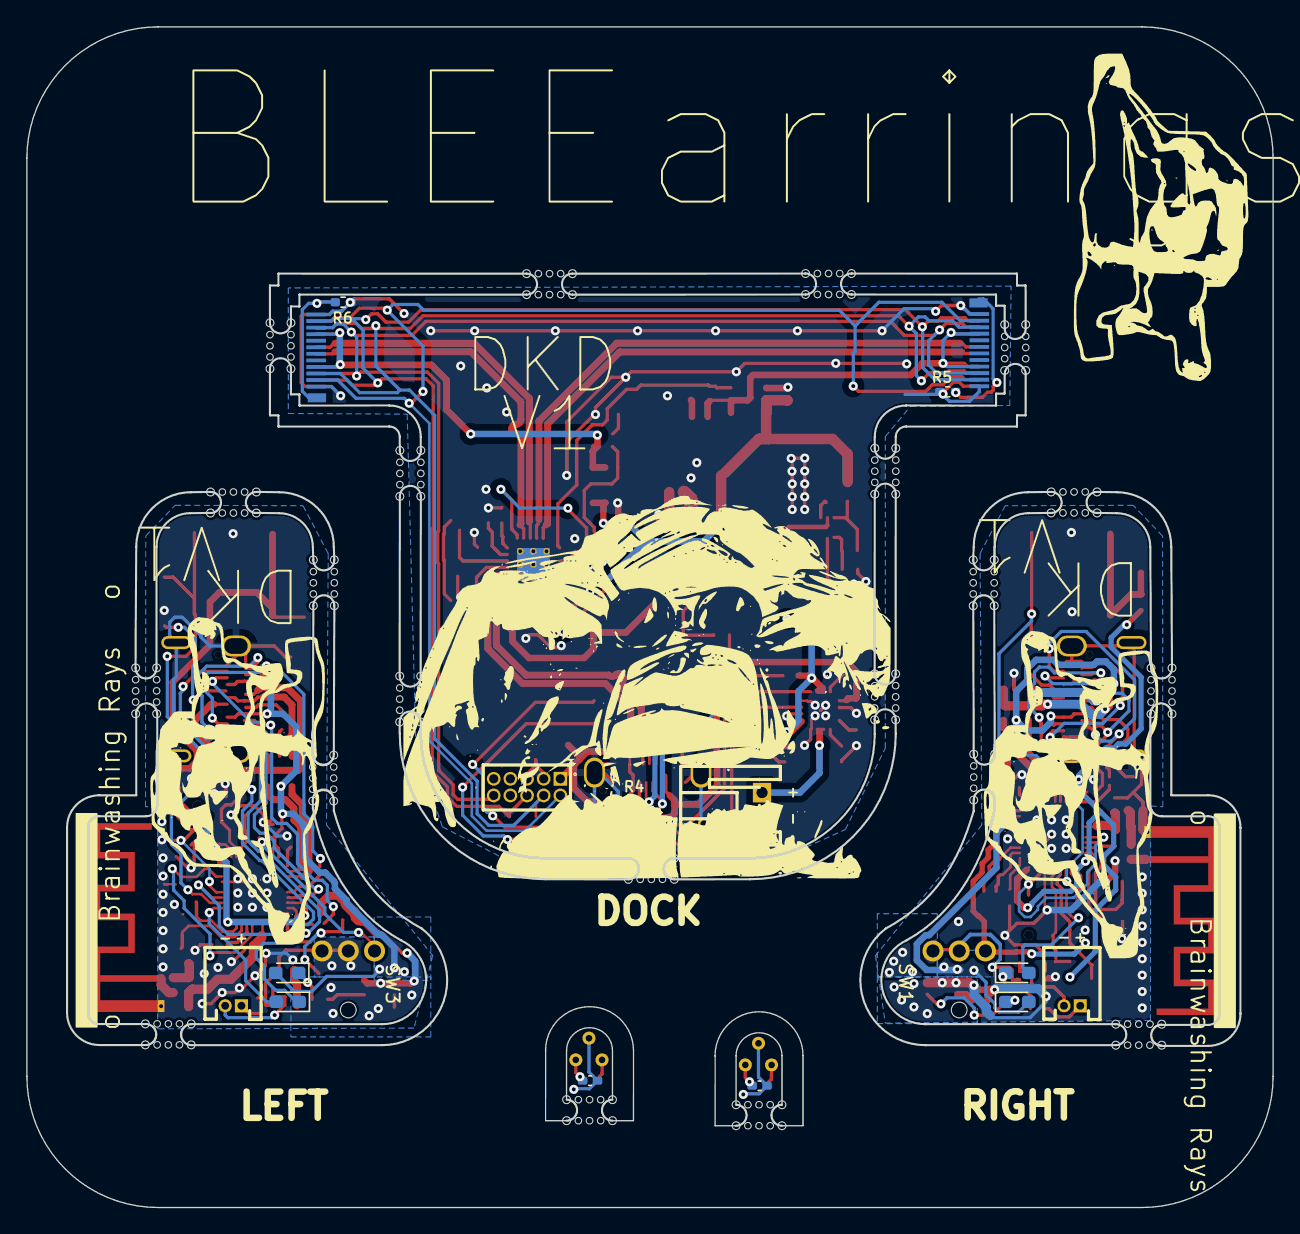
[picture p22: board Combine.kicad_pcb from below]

Board: 2 copper layers, 95.0 x 90.0 mm, 194 parts (15 on the bottom side), 135 nets.

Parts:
ANT1, ANT2: Texas_SWRA117D_2.4GHz_Left
BT1: Battery Pimoroni 1200mAh; CONN-TH_S2B-PH-K-S-LF-SN
BT2, BT3: Battery Gens ace 200mAh 1S 45C 3.7V; CONN-TH_530480210
C1, C2, C11, C13, C16, C18, C19, C20, C25, C30, C33, C41, C46, C49, C57, C60, C63, C64: 100n; C_0402_1005Metric_Pad0.74x0.62mm_HandSolder
C3, C12, C14, C23, C34, C38, C50, C54: 1u; C_0402_1005Metric_Pad0.74x0.62mm_HandSolder
C4, C5: 2.2u; C_0402_1005Metric_Pad0.74x0.62mm_HandSolder
C6, C7, C15, C17, C28, C29, C31, C44, C45, C47: 4.7u; C_0402_1005Metric_Pad0.74x0.62mm_HandSolder
C8, C24, C26, C59, C61: 10u; C_0402_1005Metric_Pad0.74x0.62mm_HandSolder
C9, C10: 22u; C_0603_1608Metric_Pad1.08x0.95mm_HandSolder
C21, C22: 18p; C_0402_1005Metric_Pad0.74x0.62mm_HandSolder
C27, C32, C43, C48: 8p; C_0402_1005Metric_Pad0.74x0.62mm_HandSolder
C35, C51: 1p; C_0402_1005Metric_Pad0.74x0.62mm_HandSolder
C36, C52: 100p; C_0402_1005Metric_Pad0.74x0.62mm_HandSolder
C37, C53: 1.2p; C_0402_1005Metric_Pad0.74x0.62mm_HandSolder
C39, C55: NC; C_0402_1005Metric_Pad0.74x0.62mm_HandSolder
C40, C42, C56, C58: 12p; C_0402_1005Metric_Pad0.74x0.62mm_HandSolder
D1: LED; LED_0603_1608Metric_Pad1.05x0.95mm_HandSolder
D2: BLUE RED; LED_0603_1608Metric_Pad1.05x0.95mm_HandSolder
D3, D4, D5, D8, D10: BLUE LED; LED_0603_1608Metric_Pad1.05x0.95mm_HandSolder
D6, D9: USBLC6-2SC6_C2687116; SOT-23-6_L2.9-W1.6-P0.95-LS2.8-BL
D7, D11: RED LED; LED_0603_1608Metric_Pad1.05x0.95mm_HandSolder
D12, D13: 2758; LED-SMD_4P-L1.6-W1.5_XL-1615RGBC-WS2812B
J1, J3, J6: USB_C_Receptacle; TYPE-C-SMD_C9900025773
J2: Conn_01x10_Socket; HDR-TH_10P-P1.27-V-M-R2-C5-S1.27-1
J4, J7: Screw_Terminal_01x01; CONN-SMD_custom1
J5, J8: Screw_Terminal_01x02; CONN-SMD_2059-302
L1: 4.7u; IND-SMD_L4.5-W4.1
L2, L4: 4.7n; L_0402_1005Metric_Pad0.77x0.64mm_HandSolder
L3, L5: 2.2n; L_0402_1005Metric_Pad0.77x0.64mm_HandSolder
P1, P2: USB_C_Plug; USB-C-SMD_TYPE-C-24P-GTJB-040
R1, R4, R24, R25, R38, R39: 5k1; R_0402_1005Metric_Pad0.72x0.64mm_HandSolder
R5, R6, R11, R12: 1k; R_0402_1005Metric_Pad0.72x0.64mm_HandSolder
R7: 1.18k; R_0402_1005Metric_Pad0.72x0.64mm_HandSolder
R8: 1.78k; R_0402_1005Metric_Pad0.72x0.64mm_HandSolder
R9, R21, R22, R23: 10k; R_0402_1005Metric_Pad0.72x0.64mm_HandSolder
R10, R26, R37, R48, R49: 2k; R_0402_1005Metric_Pad0.72x0.64mm_HandSolder
R13: 732; R_0402_1005Metric_Pad0.72x0.64mm_HandSolder
R14, R34, R45: 100k; R_0402_1005Metric_Pad0.72x0.64mm_HandSolder
R15, R16, R29, R40: 220; R_0402_1005Metric_Pad0.72x0.64mm_HandSolder
R17, R18, R19, R28, R51: 100; R_0402_1005Metric_Pad0.72x0.64mm_HandSolder
R20: 12k; R_0402_1005Metric_Pad0.72x0.64mm_HandSolder
R27, R50: 4k99; R_0402_1005Metric_Pad0.72x0.64mm_HandSolder
R30, R31, R32, R33, R41, R42, R43, R44: NF; R_0201_0603Metric
R35, R46: 33k; R_0402_1005Metric_Pad0.72x0.64mm_HandSolder
R36, R47: 470; R_0402_1005Metric_Pad0.72x0.64mm_HandSolder
SW1, SW3: TK-6580B-1; SW-TH_TK-6580B-1
SW2, SW4: SW_DIP_x01; KEY-SMD_L3.0-W2.5-LS4.0
TP1, TP2, TP3, TP4, TP5, TP6, TP7, TP8, TP9, TP10, TP11, TP12, TP13, TP14, TP15, TP17, TP18, TP19, TP28: TestPoint; TestPoint_Pad_D1.0mm
TP16, TP20: TestPoint; TestPoint_Pad_D2.0mm
TP21, TP22, TP23, TP24, TP25, TP26: TestPoint; TestPoint_THTPad_D1.0mm_Drill0.5mm
TPL3: TestPoint; TestPoint_Pad_D1.0mm
U1: AMS1117-3.3; SOT-223-3_TabPin2
U2: BQ24073RGT; VQFN-16-1EP_3x3mm_P0.5mm_EP1.6x1.6mm
U3: TPS61023DRLR; SOT-563_L1.6-W1.2-P0.50-LS1.6-BR
U4, U6: SIP32509DT-T1-GE3; SOT-23-6_Handsoldering
U5: USB2422T-I/MJ; HVQFN-24-1EP_4x4mm_P0.5mm_EP2.5x2.5mm_ThermalVias
U7, U11: MCP73831T-2ACI/OT; SOT-23-5_L3.0-W1.7-P0.95-LS2.8-BL
U8, U12: XB6096I2SV; WDFN-6_L2.0-W2.0-P0.65-BL-EP
U9, U10: NRF52833-QDAA-R7; QFN-40_L5.0-W5.0-P0.40-TL-EP3.6
Y1: X322524MOB4SI; CRYSTAL-SMD_4P-L3.2-W2.5-BL
Y2, Y4: X161032768KLD2SI; CRYSTAL-SMD_L1.6-W1.0
Y3, Y5: XL7EL89CKI-111YLC-32M; CRYSTAL-SMD_4P-L2.0-W1.6-BL

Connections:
+3V3_1: C5.1, C11.2, C12.2, C19.2, R10.2, R23.2, TP7.1, U1.2 (VO), U5.1 (VDD33), U5.9 (VDD33), U5.18 (VDD33)
+3V3_2: C30.1, C34.2, R36.2, R37.2, U9.18 (VDD), U9.30 (VDD), U9.40 (VDD)
+3V3_3: C46.1, C50.2, R47.2, R48.2, U10.18 (VDD), U10.30 (VDD), U10.40 (VDD)
+BATT_1: C28.2, R34.2, SW1.3, U9.9 (VDDH)
+BATT_2: C44.2, R45.2, SW3.3, U10.9 (VDDH)
/Dock/DeviceSelect/D+: J1.A6 (D+), J1.B6 (D+), U5.20 (USBDP_UP)
/Dock/DeviceSelect/D-: J1.A7 (D-), J1.B7 (D-), U5.19 (USBDM_UP)
/Dock/DeviceSelect/D_1+: P2.A6 (D+), U5.3 (USBDP_DN1/PRT_DIS_P1)
/Dock/DeviceSelect/D_1-: P2.A7 (D-), U5.2 (USBDM_DN1/PRT_DIS_M1)
/Dock/DeviceSelect/D_2+: P1.A6 (D+), U5.5 (USBDP_DN2/PRT_DIS_P2)
/Dock/DeviceSelect/D_2-: P1.A7 (D-), U5.4 (USBDM_DN2/PRT_DIS_M2)
/Dock/DeviceSelect/VBUS1: C13.2, P2.A4 (VBUS), P2.A9 (VBUS), P2.B4 (VBUS), P2.B9 (VBUS), R16.1, TP11.1, U4.1 (OUT), U4.2 (OUT)
/Dock/DeviceSelect/VBUS2: C16.2, P1.A4 (VBUS), P1.A9 (VBUS), P1.B4 (VBUS), P1.B9 (VBUS), R15.1, TP12.1, U6.1 (OUT), U6.2 (OUT)
/Dock/DeviceSelect/Vsys: C4.1, C9.1, C10.1, C15.2, C17.2, R13.2, R21.2, TP10.1, U1.3 (VI), U3.6 (VOUT), U4.5 (IN), U4.6 (IN), U6.5 (IN), U6.6 (IN)
/Dock/ExtraBattery/3.7Out: C7.1, C8.1, L1.1, R11.2, R12.2, TP9.1, U2.5 (EN2), U2.10 (OUT), U2.11 (OUT), U3.2 (EN), U3.3 (VIN)
/Dock/ExtraBattery/FB: R13.1, R14.2, U3.1 (FB)
/Dock/ExtraBattery/VBAT: BT1.1 (+), C6.1, TP8.1, U2.2 (BAT), U2.3 (BAT)
/EarringL/DSP/VBUS: C45.2, C61.1, D9.5 (VBUS), D11.2 (A), J6.A4 (VBUS), U10.10 (VBUS), U11.4 (VDD)
/EarringL/DSP/nReset: J6.A10 (RX2-), J6.B10 (RX1-), R43.1
/EarringL/LUSBd+: D9.3 (I/O2), J6.A6 (D+), J6.B6 (D+)
/EarringL/LUSBd-: D9.1 (I/O1), J6.A7 (D-), J6.B7 (D-)
/EarringL/Power/VBAT: C59.1, C60.1, R51.2, SW3.1, SW3.2, U11.3 (VBAT), U12.1 (VDD)
/EarringR/DSP/VBUS: C26.1, C29.2, D6.5 (VBUS), D7.2 (A), J3.A4 (VBUS), U7.4 (VDD), U9.10 (VBUS)
/EarringR/DSP/nReset: J3.A10 (RX2-), J3.B10 (RX1-), R32.1
/EarringR/Power/VBAT: C24.1, C25.1, R28.2, SW1.1, SW1.2, U7.3 (VBAT), U8.1 (VDD)
BatRef_1: R34.1, R35.2, TP13.1, U9.34 (P0.29_AIN5)
BatRef_2: R45.1, R46.2, TP17.1, U10.34 (P0.29_AIN5)
D1+: D6.4 (I/O2), U9.13 (D+)
D1-: D6.6 (I/O1), U9.12 (D-)
D2+: D9.4 (I/O2), U10.13 (D+)
D2-: D9.6 (I/O1), U10.12 (D-)
DEC6_1: C38.1, C39.1, U9.26 (DEC6), U9.38 (DEC4)
DEC6_2: C54.1, C55.1, U10.26 (DEC6), U10.38 (DEC4)
GND1: BT1.2 (-), C1.1, C2.1, C3.2, C4.2, C5.2, C6.2, C7.2, C8.2, C9.2, C10.2, C11.1, C12.1, C14.1, C15.1, C17.1, C18.1, C19.1, C20.1, C21.2, C22.1, C23.1, D1.1 (K), D4.1 (K), D5.1 (K), J1.A1 (GND), J1.S1 (SHIELD), J2.3, J2.5, P1.A1 (GND), P2.A1 (GND), R1.1, R4.1, R5.2, R6.2, R7.2, R8.2, R9.1, R14.1, R17.1, R18.1, R19.1, R20.1, R22.1, TP1.1, U1.1 (GND), U2.4 (~CE), U2.6 (EN1), U2.8 (VSS), U2.14 (TMR), U2.17 (VSS), U3.4 (GND), U4.4 (GND), U5.25 (EP), U6.4 (GND), Y1.1, Y1.3
GND2: ANT1.2 (GND), C24.2, C25.2, C26.2, C27.1, C28.1, C29.1, C30.2, C31.1, C32.1, C33.1, C34.1, C35.2, C36.2, C37.2, C38.2, C39.2, C40.1, C41.1, C42.1, D6.2 (GND), J3.A1 (GND), J3.S1 (SHIELD), J5.2, R24.1, R25.1, R27.2, R29.1, R35.1, SW2.2, TP16.1, U7.2 (VSS), U8.4 (VM), U8.5 (VM), U8.6 (VM), U9.37 (VSS), U9.41 (VSS), Y3.2, Y3.3
GND3: ANT2.2 (GND), C43.1, C44.1, C45.1, C46.2, C47.1, C48.1, C49.1, C50.1, C51.2, C52.2, C53.2, C54.2, C55.2, C56.1, C57.1, C58.1, C59.2, C60.2, C61.2, D9.2 (GND), J6.A1 (GND), J6.S1 (SHIELD), J8.2, R38.1, R39.1, R40.1, R46.1, R50.2, SW4.2, TP20.1, U10.37 (VSS), U10.41 (VSS), U11.2 (VSS), U12.4 (VM), U12.5 (VM), U12.6 (VM), Y5.2, Y5.3
LED_A_1: D8.2 (A), U9.32 (P0.02_AIN0)
LED_A_2: D10.2 (A), U10.32 (P0.02_AIN0)
NEO_LED_1: J4.1, TP14.1, U9.33 (P0.28_AIN4)
NEO_LED_2: J7.1, TP18.1, U10.33 (P0.28_AIN4)
unnamed: ANT1.1 (FP), L3.2
unnamed: ANT2.1 (FP), L5.2
unnamed: BT2.1 (+), R28.1
unnamed: BT2.2 (-), U8.2 (GND), U8.3 (GND), U8.7 (EP)
unnamed: BT3.1 (+), R51.1
unnamed: BT3.2 (-), U12.2 (GND), U12.3 (GND), U12.7 (EP)
unnamed: C37.1, L2.2, L3.1
unnamed: C53.1, L4.2, L5.1
unnamed: D1.2 (A), R10.1
unnamed: D2.2 (A), R11.1
unnamed: D2.1 (K), U2.7 (~PGOOD)
unnamed: D3.2 (A), R12.1
unnamed: D3.1 (K), U2.9 (~CHG)
unnamed: D4.2 (A), R15.2
unnamed: D5.2 (A), R16.2
unnamed: D6.1 (I/O1), J3.A7 (D-), J3.B7 (D-)
unnamed: D6.3 (I/O2), J3.A6 (D+), J3.B6 (D+)
unnamed: D7.1 (K), R26.1
unnamed: D8.1 (K), R29.2
unnamed: D10.1 (K), R40.2
unnamed: D11.1 (K), R49.1
unnamed: D12.4 (DIN), TP21.1
unnamed: C63.2, D12.1 (VDD), TP22.1
unnamed: C63.1, D12.3 (VSS), TP23.1
unnamed: D13.4 (DIN), TP24.1
unnamed: C64.2, D13.1 (VDD), TP25.1
unnamed: C64.1, D13.3 (VSS), TP26.1
unnamed: J1.A5 (CC1), R1.2
unnamed: J1.B5 (CC2), R4.2
unnamed: J3.A5 (CC1), R24.2
unnamed: J3.B5 (CC2), R25.2
unnamed: J5.1, R36.1, TP15.1
unnamed: J6.A5 (CC1), R38.2
unnamed: J6.B5 (CC2), R39.2
unnamed: J8.1, R47.1, TP19.1
unnamed: C1.2, P1.S1 (SHIELD), R5.1
unnamed: C2.2, P2.S1 (SHIELD), R6.1
unnamed: R7.1, U2.12 (ILIM)
unnamed: R8.1, U2.16 (ISET)
unnamed: R9.2, U2.1 (TS)
unnamed: L1.2, U3.5 (SW)
unnamed: C14.2, U5.10 (CRFILT)
unnamed: C20.2, U5.23 (PLLFILT)
unnamed: R20.2, U5.24 (RBIAS)
unnamed: R18.2, U5.14 (SMBCLK/CFG_SEL0)
unnamed: R17.2, U5.13 (SMBDATA/NON_REM1)
unnamed: R19.2, U5.17 (SUSP_IND/LOCAL_PWR/(NON_REM0))
unnamed: C18.2, R21.1, R22.2, U5.16 (VBUS_DET)
unnamed: C22.2, U5.22 (XTALIN/CLKIN), Y1.2
unnamed: C21.1, U5.21 (XTALOUT/(CLKIN_EN)), Y1.4
unnamed: R27.1, U7.5 (PROG)
unnamed: R26.2, U7.1 (STAT)
unnamed: C35.1, L2.1, U9.24 (ANT)
unnamed: C33.2, U9.1 (DEC1)
unnamed: C36.1, U9.27 (DEC3)
unnamed: C31.2, U9.11 (DECUSB)
unnamed: C27.2, U9.2 (P0.00_XL1), Y2.2
unnamed: C32.2, U9.3 (P0.01_XL2), Y2.1
unnamed: TPL3.1, U9.31 (P0.03_AIN1)
unnamed: R32.2, U9.16 (P0.18_nRESET)
unnamed: R30.1, U9.17 (P0.20)
unnamed: R31.1, U9.20 (SWDCLK)
unnamed: R33.2, U9.19 (SWDIO)
unnamed: C42.2, U9.28 (XC1), Y3.1
unnamed: C40.2, U9.29 (XC2), Y3.4
unnamed: C51.1, L4.1, U10.24 (ANT)
unnamed: C49.2, U10.1 (DEC1)
unnamed: C52.1, U10.27 (DEC3)
unnamed: C47.2, U10.11 (DECUSB)
unnamed: C43.2, U10.2 (P0.00_XL1), Y4.2
unnamed: C48.2, U10.3 (P0.01_XL2), Y4.1
unnamed: R43.2, U10.16 (P0.18_nRESET)
unnamed: R41.1, U10.17 (P0.20)
unnamed: R42.1, U10.20 (SWDCLK)
unnamed: R44.2, U10.19 (SWDIO)
unnamed: C58.2, U10.28 (XC1), Y5.1
unnamed: C56.2, U10.29 (XC2), Y5.4
unnamed: R50.1, U11.5 (PROG)
unnamed: R49.2, U11.1 (STAT)
PWREN1: C13.1, U4.3 (EN), U5.11 (PRTPWR2)
PWREN2: C16.1, TP28.1, U5.7 (PRTPWR1/(BC_EN1)), U6.3 (EN)
Pair_1: C41.2, R37.1, SW2.1, U9.35 (P0.30_AIN6)
Pair_2: C57.2, R48.1, SW4.1, U10.35 (P0.30_AIN6)
RESET: C23.2, R23.1, U5.15 (RESET_N)
SWCLK: J2.4, P1.A3 (TX1-), P1.B3 (TX2-), P2.A3 (TX1-), P2.B3 (TX2-), TP2.1
SWDCLK_L_1: J3.A3 (TX1-), J3.B3 (TX2-), R33.1
SWDCLK_L_2: J6.A3 (TX1-), J6.B3 (TX2-), R44.1
SWDIO: J2.2, P1.A2 (TX1+), P1.B2 (TX2+), P2.A2 (TX1+), P2.B2 (TX2+), TP6.1
SWDIO_L_1: J3.A2 (TX1+), J3.B2 (TX2+), R31.2
SWDIO_L_2: J6.A2 (TX1+), J6.B2 (TX2+), R42.2
SWO: J2.6, P1.A11 (RX2+), P1.B11 (RX1+), P2.A11 (RX2+), P2.B11 (RX1+), TP5.1
SWO_L_1: J3.A11 (RX2+), J3.B11 (RX1+), R30.2
SWO_L_2: J6.A11 (RX2+), J6.B11 (RX1+), R41.2
VTRef: C3.1, J1.A4 (VBUS), J2.1, TP3.1, U2.13 (IN)
nRESET: J2.10, P1.A10 (RX2-), P1.B10 (RX1-), P2.A10 (RX2-), P2.B10 (RX1-), TP4.1

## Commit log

2022-12-08 Toast To Success
    Button Added to App
2023-09-26 Schematic Started
    [BLEEarrings.kicad_pcb, BLEEarrings.kicad_sch]
2023-10-02 More KiCAD Work
    More KiCAD work complete
    [BLEEarrings.kicad_sch, DSP.kicad_sch, Power.kicad_sch]
2023-10-30 First Draft Schematic Done
    - Symbols and footprints checked
    - Dom added to repo
    - Centralised footprints created
    [BLEEarrings.kicad_pcb, BLEEarrings.kicad_sch, DSP.kicad_sch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]
2023-11-23 Improved Antenna Layout
    - Initial layout complete
    - TO DO:
    - Test points
    - Curved Tracks
    - Silkscreen
    - Check antenna
    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
    [BLEEarrings.FCStd, BLEEarrings.kicad_pcb, BLEEarrings.kicad_sch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]
2023-12-06 Large Update
    [2Wayconn.FCStd, 2wayconn.blend, 2wayconn.step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]
2023-12-07 Small Bits
    [BLEEarrings.kicad_pcb, BLEEarrings.kicad_sch, DSP.kicad_sch]
2023-12-08 New Chip NRF52833
    large changes
    [BLEEarrings.kicad_pcb, BLEEarrings.kicad_sch, Charging.kicad_sch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]
2023-12-12 Dock Updates
    [BLEEarrings.kicad_pcb, BLEEarrings.kicad_sch, DSP.kicad_sch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]
2024-01-08 Routing Started on Earrings Again
    - Only small routing changes made
    [BLEEarrings.kicad_pcb, BLEEarrings.kicad_sch, DSP.kicad_sch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]
2024-02-22 Ignoring Backups
    More Dock progress
    All local backups removed
    [BLEEarrings.kicad_pcb, BLEEarrings.kicad_sch, DSP.kicad_sch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]
2024-02-22 Beautiful Skilkscreen Added
    Dock schematic intial draft complete
    [BLEEarrings.kicad_pcb, BLEEarrings.kicad_sch, DeviceSelect.kicad_sch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]
2024-02-22 Small Updates
    [BLEEarrings.kicad_pcb, Dock.kicad_pcb, Dock.kicad_sch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]
2024-02-22 Dock Updates
    Starting to layout the dock
    Dom still to check
    [Dock.kicad_pcb, Dock.kicad_sch, DockBattery.kicad_sch]
2024-02-23 Initial Dock DRC Complete
    [BLEEarrings.kicad_pcb, Battery.FCStd, BatteryDock.STEP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]
2024-03-01 Starting the Panel
    [BLEEarrings.kicad_pcb, BLEEarrings.kicad_sch, Combine.kicad_pcb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]
2024-03-27 Started mirror earrings and case
    [BLEEarrings.kicad_pcb, BLEEarrings_Mirror.kicad_pcb, Dock.kicad_pcb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]
2024-04-28 Completing the combined layout
    [BLEEarrings.kicad_pcb, BLEEarrings.kicad_sch, BLEEarrings.obj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]
2024-04-28 Schem rev 1 pt1
    [Combine.kicad_pcb, DeviceSelect.kicad_sch, Dock.kicad_sch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]
2024-12-20 V1 BUILD
    [2Wayconn.FCStd, 2wayconn.blend, 2wayconn.step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]
